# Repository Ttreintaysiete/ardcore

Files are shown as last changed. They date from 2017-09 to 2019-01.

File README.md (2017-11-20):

# Eurorack Ardcore 2017
This is the repository for the tuned sketches, schematics and board files of the new 2017 version 20Objects Ardcore. The Ardcore is an Arduino based module created by Darwin Grosse as his final work for MS. You can find more information on the orignal project in his website http://20objects.com/ardcore/.

So far there are a couple of versions of the ardcore, the original one by 20Objects which was a PCB only, AFAIK it was intended for dotcom and 5U formats and all the wiring with the panel has to be done manually. This version has 4 AnalogInputs, 2 of them are potentiometers and the other 2 are inputs. It also has 2 digital outputs (i.e. for triggers).

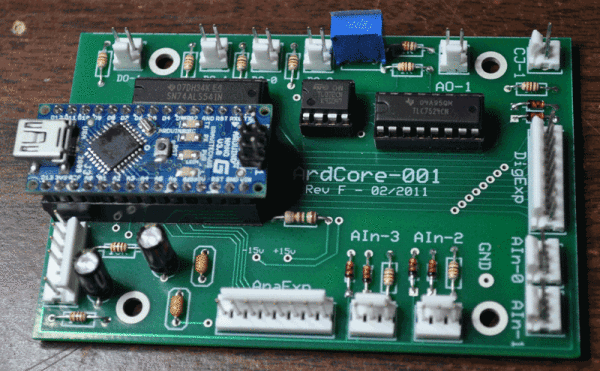
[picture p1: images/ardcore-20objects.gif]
original ardcore


The [original sketches](https://github.com/darwingrosse/ArdCore-Code/commits/master) were first published by Darwin back in 2012. This project originally was a DIY PCB only project.

Later on SnazzyFX published an eurorack format of the module and (as Dan a.k.a. told me) it was long out of stock due its success for a couple of years. 

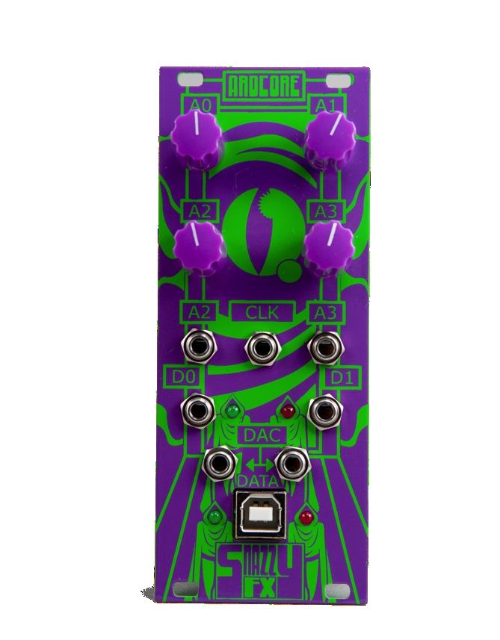
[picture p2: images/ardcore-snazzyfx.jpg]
snazzyfx ardcore


There are plenty of threads in muffwiggler talking about different DIY versions, back in 2013 we made our own version for bananas.

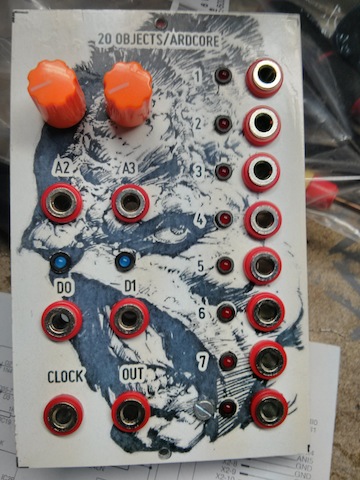
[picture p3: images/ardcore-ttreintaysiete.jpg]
snazzyfx ardcore


The Ardcore is not so well known module but its a power house due its flexibility, it has several sketches that are very usefull and fun to play, but more important the Ardcore is a module that tries to embed the Arduino philosophy into the modular synthesizer community which is to allow musicians, artists and engineers to easly create microcontroller based modules.

Due its digital nature, the ardcore is very good for creating CV sources that are otherwise more complex to create with hardware (like a drunken walk), but it also can create audio with the DAC.

# Our implementation of Ardcore

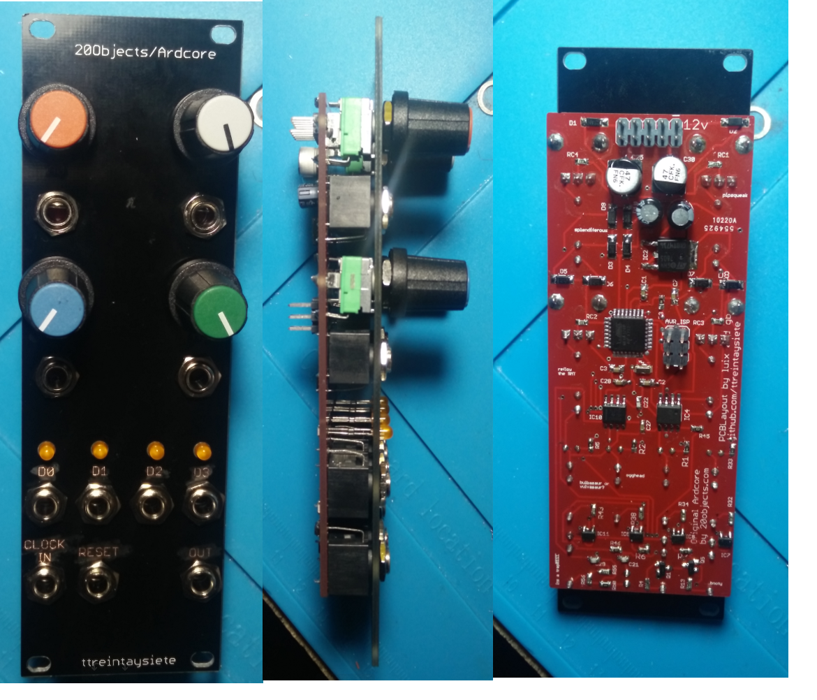
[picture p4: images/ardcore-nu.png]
nu ardcore


So we decided to make a skiff friendly, DIY Ardcore with several improvements:

* double the number of __analog inputs__. So now each AnalogInput has a potentiometer that is normalized to 5v when nothing is connected, when you plug something into the corresponding jack you can still use the potentiometer to attenuate the incommin signal. All analog inputs are protected with diodes (1n4148) so voltage will be cliped to the microcontroller range always (0v-5v). In any case you can use the pot as mentioned to attenuate the incomming signal.

* double the number of __digital outputs__. The original ardcore had 2 digital outputs, in this version we put D2 and D3 for a total of 4. This outputs are driven by the Tristate buffer widely used in digital modules like Mutable Instruments, so you can both isolate microcontroller pin from the outside world at the same time to upscale the voltage and buffer it. So if you plug an output signal into the digital outputs you can't damage the micro controller.

* double the number of __digital inputs__, the original and snazzy Ardcore had 1 multipurpouse digital input labeled as "clock". This input is connected to a pin in the micro controler with support for interrupts which are very usefull when you want to have "responsive" or non blocking behaviours on your sketch. In the new ardcore we added a second digital input labeled __RESET__ which is also connected to another interrupt pin. All the existing sketches were created for the previous hardware versions of the ardcore so they __don't__ use this pin.

* Upgraded DAC, from parallel to SPI and from 8bit to 12bit. This upgrade was both a must go mainly because of the size of the IC and that its easy to source it, also the PCB has less trace (since parallel communication uses 8 connections from atmega328 to the DAC, in comparison with the SPI that only uses 3 wires.

* 8hp Skiff friendly.

# The bad things

Some of the decissions taken during the pcb design have downsides.

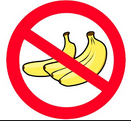
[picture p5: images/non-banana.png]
no more fruit-of-love


* This version of the Ardcore is __non-banana friendly__ :( ... we are very sorry for this because we have many modules in bananas and love them, but it was a design decision to make it work with the disconnections on the minijacks. This is by far (in our opinion) the biggest downside.

* When upgrading the DAC from parallel to SPI we lose all the "bit" traces from the parallel connections, so its not possible to easly create an expander for this version of the module.

* Another problem from upgrading the DAC is that the original sketches that used it, need a small tweak on the code in order to work properlly. This is based on the Euroardcore but with the mcp4921

  * you need to add to the beggining of any sketch using the DAC,
    ```
    #include <SPI.h>
    #include <DAC_MCP49xx.h>
    DAC_MCP49xx dac(DAC_MCP49xx::MCP4921, 10);
    ```
  * also you need to add the following code at the end of the __setup()__ so the DAC is properlly initialized:
    ```
    dac.setBuffer(true);        //  Set FALSE for 5V vref.
    dac.setGain(1);             //  "1" for 5V vref. "2" for 2.5V vref.
    dac.setPortWrite(true); 
    ```
  * and finally replace the __dacOutput()__ and __dacOutputfast()__ to be something like:
    ```
     void dacOutput(long v)
    {
      dac.outputA(v);
    }
    ```

* No USB, need a programer.. the original Ardcore had either an arduino nano or a ftdi IC with USB on the board, so you can directly upload your sketches. With this version you need an external programmer that uses ISP, we recommend the official [AVRISP mkii](http://www.atmel.com/tools/avrispmkii.aspx).

# License:

This software and hardware is licensed under the Creative Commons __Attribution-NonCommercial__ license. This license allows you to tweak and build upon the code for non-commercial purposes, without the requirement to license derivative works on the same terms. If you wish to use this (or derived) work for commercial work or usage of the PCBS, please contact 20 Objects LLC its website (www.20objects.com).

For more information on the Creative Commons CC BY-NC license, visit http://creativecommons.org/licenses/

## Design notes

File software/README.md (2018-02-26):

# MCP Library

In order to compile sketches using the MCP49 DAC, you have to download the library [here](https://github.com/downloads/exscape/electronics/Arduino_DAC_MCP49x1_v1.0.zip) and install it in your Arduino library. Also note that some instructions used in the fac_drums were deprecated on the newest Arduino IDE, so you need to compile and upload them on the older.

You need to do a small tweak on the code in order to work properlly, this is because this new DAC uses SPI. This is based on the Euroardcore but with the mcp4921 has [been fully tested](https://www.youtube.com/watch?v=P1rAHDsiEtc):

  * you need to add to the beggining of any sketch using the DAC,
    ```
    #include <SPI.h>
    #include <DAC_MCP49xx.h>
    DAC_MCP49xx dac(DAC_MCP49xx::MCP4921, 10);
    ```
  * also you need to add the following code at the end of the __setup()__ so the DAC is properlly initialized:
    ```
    dac.setBuffer(true);        //  Set FALSE for 5V vref.
    dac.setGain(1);             //  "1" for 5V vref. "2" for 2.5V vref.
    dac.setPortWrite(true); 
    ```
  * and finally replace the __dacOutput()__ and __dacOutputfast()__ to be something like:
    ```
     void dacOutput(long v)
    {
      dac.outputA(v);
    }
    ```

# Compiling the sketches of this repo

I'm using __arduino 1.0.6__ to compile all fac_drum sketches, it may be possible to use newer arduino versions on the rest of the sketches.

In the __libraries__ folder you can find the library I'm currently using to compile all the sketches with the MCP (dac).

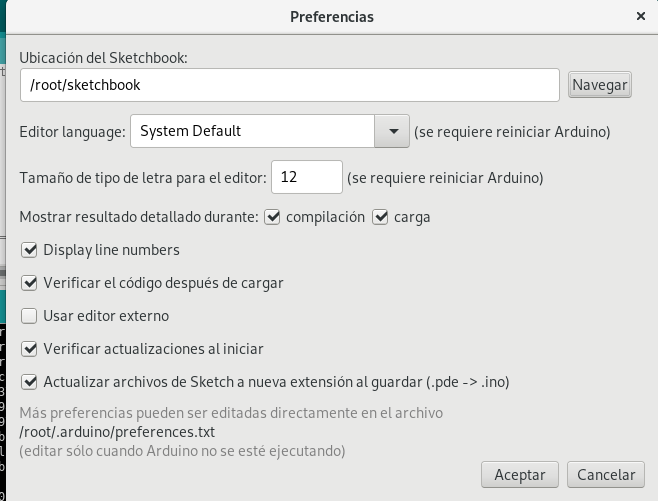
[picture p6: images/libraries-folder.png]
lib configuration ardcore


In my case I'm using Arduino with sudo command (to let read/write USB ports for the programmer), so my __sketbook__ is located at __/root/sketchbook__ and here is were I coped the DAC_MCP49xx library.

```
[root@boxita sketchbook]# tree
.
└── libraries
    ├── DAC_MCP49xx
    │   ├── DAC_MCP49xx.cpp
    │   ├── DAC_MCP49xx.h
    │   ├── examples
    │   │   ├── MCP49x1_single_demo
    │   │   │   └── MCP49x1_single_demo.ino
    │   │   └── MCP49x2_dual_demo
    │   │       └── MCP49x2_dual_demo.ino
    │   ├── keywords.txt
    │   └── README.txt
    └── readme.txt

5 directories, 8 files
[root@boxita sketchbook]# 
```

# Uploading hex using __avrdude__ and your AVRISP mkII.

To upload the file directly you can try the following command, I'm doing this on linux (Arch) so depending on your system configuration you may need to __sudo__ the command. Remember to burn the fuses as explained in the building guide.

```
$ avrdude -c avrispmkII -p ATmega328P -e -U flash:w:fac_fm_osc.cpp.hex
```

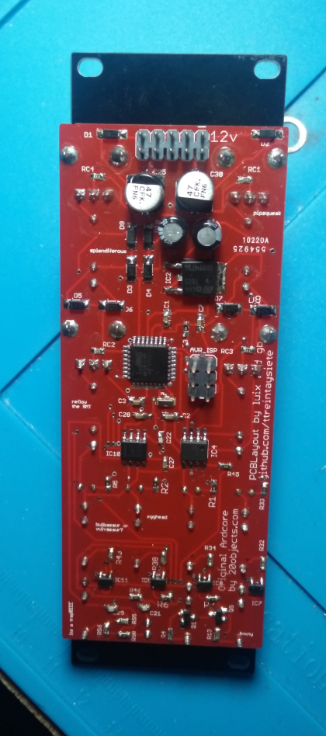
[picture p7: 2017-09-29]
images/ardcore-nu-back.png

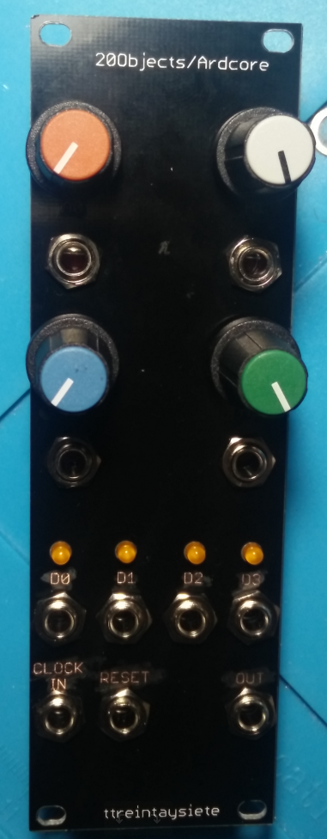
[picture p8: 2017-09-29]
images/ardcore-nu-frontal.png

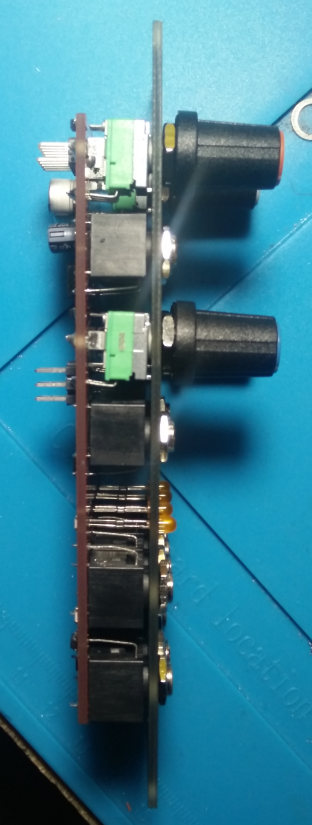
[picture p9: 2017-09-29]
images/ardcore-nu-side-skiff.png

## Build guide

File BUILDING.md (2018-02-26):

# Bill of Materials

This is the mouser [BOM](https://www.mouser.es/ProjectManager/ProjectDetail.aspx?AccessID=9c269e6775), but here is the detail anyway because you are so lazy to copy paste it into a mouser project/cart :P

Suggested Part | Qty | Value | Parts | Description
---------------| --- | ----- | ----- | ------------
[9mm Alpha pots](https://www.thonk.co.uk/shop/alpha-9mm-pots-dshaft/) | 4 | 10k | ALPS_POT_VERTICAL       
[thonkicons](https://www.thonk.co.uk/shop/3-5mm-jacks/) | 11 | WQP-PJ301M-12_JACK | WQP-PJ301M-12_JACK      
n/a | 1 | Header 3x2 | AVR_ISP | Header 3x2
n/a | 1 | Header 5x2  | JP1 | Header 5x2
n/a | 4 | LED3MM | LED1, LED2, LED3, LED4  LED
81-GRM188R71H104JA3D | 6 | 100n | C1, C2, C3, C7, C27, C28 | CAPACITOR, European symbol
81-GRM1885C1H101GA1J | 2 | 100p | C21, C22 | CAPACITOR, American symbol
667-EEE-FK1C470P | 2 | 47u | C25, C30 | POLARIZED CAPACITOR, American symbol
81-GRM39C470J50 | 1 | 47p | C29 | CAPACITOR, American symbol
667-ECE-A1VKS100 | 3 | 10u | C4, C5, C6 | POLARIZED CAPACITOR, European symbol
621-1N5819HW-F | 2 | 1N5819HW | D1, D2 | DIODE
78-1N4148W-E3-08 | 8 | 1n4148 | D3, D4, D5, D6, D7, D8, D9, D10 | 1N4148 General Purpose Rectifie
595-TL072CD | 1 | TL072 | IC10 | OP AMP
511-L7805CDT-TR | 1 | 7805DT | IC2 | Positive VOLTAGE REGULATOR
579-MCP4921-E/SN | 1 | MCP4921 | IC4 
595-SN74AHCT1G125DBV | 4 | 74AHCT1G125DBV | IC5, IC7, IC8, IC11 | Single Bus Buffer Gate with 3-State Output
556-ATMEGA328P-AU | 1 | ATMEGA328P-AU | IC6 
863-MMBT3904LT1G | 2 | SOT23-BEC | Q1, Q5 | NPN Transistror
652-CR0603FX-2200ELF | 4 | __100 to 220__ | R1, R2, R5, R33 | Resistor for LEDS, so depends on your leds color.
652-CR0603FX-1002ELF | 3 | 10k | R3, R6, R7 | RESISTOR, American symbol
652-CR0603-FX-1003GLF | 3 | 100k | R4, R13, R56 | RESISTOR, American symbol
652-CR0603FX-3902ELF | 2 | 39k | R45, R46 | RESISTOR, American symbol
652-CR0603FX-4702ELF | 1 | 47k | R50 | RESISTOR, American symbol
652-CR0603-FX1001HLF | 9 | 1K | RC1, RC2, RC3, RC4, R32, R34, R38, R43, R55 | RESISTOR, European symbol
81-CSTCE16M0V53-R0 | 1 | RESONATOR | Y1 | Resonator

# Building your Ardcore

1. Solder all the power components as show in the picture:

   * Atmega328P-AU
   * SMD Resonator - this is the equivalent of a Crystal Oscillator plus the 2 x 22pf caps widely used in arduino boards but in a single package.
   * IC2 - 5V regulator 
   * D1, D2 - 1n5819
   * C4 (on the front side), C5, C6,  - 10u eletrolitic caps
   * C25, C30 - 47u electrolic caps
   * R3 a 10k resistor for the MC reset
   * C1, C2, C3, C7 - 100n ceramic caps
   * ISP pin header for programming
   * 2x5 pin header for power

   power supply components

2. test the power on the board, plug the eurorack power supply cable and check that nothing gets too hot, if you have a current measure tool its also a good practice to measure the module current consumption which should be a few milliamps. If you detect your module is compsuming more than 200mha then something is wrong. This way of testing your module is much better than directly plugin it into your euorack system so you avoid any damages to the rest of your modules.

3. Now its time to change the __fuses__ of the Atmega328P-AU remember you need to plug your Ardcore to your eurorack power supplyg (ribbon cable), this is important because by default the microcontrollers uses its internal oscillator (which is not very accurate, but its free), to use an external oscillator you should use the avrdude tool and this command and your AVRPISP-mkii programer:

```
[luix@boxita ardcore]$ sudo avrdude -c avrispmkII -p m328p -U lfuse:w:0xFF:m -U hfuse:w:0xDA:m -U efuse:w:0x05:m
[sudo] password for luix: 

avrdude: AVR device initialized and ready to accept instructions

Reading | ################################################## | 100% 0.00s

avrdude: Device signature = 0x1e950f (probably m328p)
avrdude: reading input file "0xFF"
avrdude: writing lfuse (1 bytes):

Writing | ################################################## | 100% 0.01s

avrdude: 1 bytes of lfuse written
avrdude: verifying lfuse memory against 0xFF:
avrdude: load data lfuse data from input file 0xFF:
avrdude: input file 0xFF contains 1 bytes
avrdude: reading on-chip lfuse data:

Reading | ################################################## | 100% 0.00s

avrdude: verifying ...
avrdude: 1 bytes of lfuse verified
avrdude: reading input file "0xDA"
avrdude: writing hfuse (1 bytes):

Writing | ################################################## | 100% 0.01s

avrdude: 1 bytes of hfuse written
avrdude: verifying hfuse memory against 0xDA:
avrdude: load data hfuse data from input file 0xDA:
avrdude: input file 0xDA contains 1 bytes
avrdude: reading on-chip hfuse data:

Reading | ################################################## | 100% 0.00s

avrdude: verifying ...
avrdude: 1 bytes of hfuse verified
avrdude: reading input file "0x05"
avrdude: writing efuse (1 bytes):

Writing | ################################################## | 100% 0.01s

avrdude: 1 bytes of efuse written
avrdude: verifying efuse memory against 0x05:
avrdude: load data efuse data from input file 0x05:
avrdude: input file 0x05 contains 1 bytes
avrdude: reading on-chip efuse data:

Reading | ################################################## | 100% 0.00s

.....

avrdude done.  Thank you.

[luix@boxita ardcore]$
```

4. Since its an Arduino based project, and it the atmega328p-au comes completely blank we have to burn the bootloader, you need to chose the board "Arduno NANO w/Atmega328" on the board menu, and change your programmer to "AVRIS-mkii" on the programmer menu. To burn the bootloader  "Tools -> Burn bootloader".

5. If everything goes OK with the bootloader now you can upload sketches, you can try to upload the [__test__](https://github.com/Ttreintaysiete/ardcore/tree/master/software/sketches/ardcore-pot-led-test) sketch we have prepared, this sketch lets you __TEST__ the LEDS, AnalogInputs and Digital Outputs, its a sort of "cheap and dirty" clock divider just mean for testing the module. It has an internal clock, it doesn't accept external clock nor uses the DAC to output anything.

6. At this point you should solder the rest of the components and check that it works with the __test sketch__. Remember to solder the jacks and the pots the last, use the panel to correctly align all the components and then solder them.

7. When you finish soldering all the components you should test your module using an sketch that uses the CLOCKIN and DAC, like th [__FAC drums__](https://github.com/Ttreintaysiete/ardcore/tree/master/software/sketches/fac_drums).

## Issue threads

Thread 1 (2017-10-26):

74AHCT1G125DBV replacement?

hedefalk, 2017-10-26:
Hi, I'm trying to source parts on a shoestring for a couple of units of this. I'm trying to avoid mouser and similar because of shipping. The only thing that was a bit problematic is the 74AHCT1G125DBV. It's not easily available on the surplus sources I'm using (mostly just aliexpress and ebay). Seems like the SOT-353 package is a lot easier to get cheap:

https://www.aliexpress.com/item/Free-Shipping-50PCS-lot-74AHCT1G125SE-7-IC-BUS-BUFF-3ST-SGL-N-INV-SOT353-125-74AHCT1G125/32682004541.html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,searchweb201602_4_10152_10065_10151_10344_10068_10345_10342_10343_10340_10341_10171_10541_10084_10083_10307_10301_5640015_10303_10060_10155_10154_10056_10055_10539_10538_5370015_10537_10312_10536_10059_10313_10314_10534_10533_100031_10103_10073_10102_10142_10107,searchweb201603_1,ppcSwitch_5&btsid=7003e7aa-5e92-4a2a-a64d-ae9a055d2782&algo_expid=900eb61a-5ea6-4e61-8745-6672c314c970-0&algo_pvid=900eb61a-5ea6-4e61-8745-6672c314c970

74AHCT1G125DBV is SOT23-5

Maybe for the next iteration :) Do you happen to know if there are any other replacements?

Thanks a lot for this work!

beeva-luisgonzalez, 2017-10-26:
Hi!
first of all thanks a lot for your message and taking time for the suggestion. This is the Mouser BOM ill be adding to the doc:

https://www.mouser.es/ProjectManager/ProjectDetail.aspx?AccessID=9c269e6775

I totally agree with all your arguments, but we wanted to make this project easy to build for anyone regarding its DIY level, so having a single "no brainer" mouser cart is the best for most cases...

Mouser is free shipping when you purchase 50€ or more which seems reasonable as your probably know, but we will consider changing this if we find a similar part in SOT-353 that is compatible.

We are using this part mainly because we copied (and trust) Mutable Instruments designs.. since Oliver uses this on most its designs.

hadesbox, 2017-10-26:
and please let us know how your build went... if you have any suggestions for the board or anything else... we tried to make it super easy to build silkscreen was carefully placed, all components have enough (we hope) space etc...

hedefalk, 2017-10-26:
Will do!

hedefalk, 2017-10-26:
I'll close the issue so it doesn't look like you're having a bug :)

hedefalk, 2017-10-26:
Just one more thing when I have you on the line :)

You recommend the AVRPISP mk2, is there a reason I can't just use an arduino as ISP, like instructions here https://www.arduino.cc/en/Tutorial/ArduinoISP

hadesbox, 2017-10-27:
@hedefalk ArduinoISP will work just fine! Its just a bit slower and if you plan to do some serious programming its better to us AVRISP mk2, but otherwise using a second arduino as programmer is fine... I'll add your link to the "programming" section as an alternative!

hadesbox, 2017-10-27:
Ohh one thing you need to test is how to change the fuses of the atmega328 because by default it has the fuses to use its internal oscillator, I added to the building doc how to do it with avrispmkii and avrdude, dont know how to do it with ArduinoISP solution... should work!

hedefalk, 2017-10-27:
Great, thanks!

Closed 2017-10-26.

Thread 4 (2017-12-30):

Placement exact between panel and component pcb?

hedefalk, 2017-12-30:
Got my PCB's from China the other day (yey!) and started on a front panel. I'm 3d printing and designing in openscad. I couldn't find a decent ruler so I extracted the values from the panel eagle file here. I noticed that the LED's are a bit displaced. My OCD wants to fix this, in your experience, would there be any problem in aligning them perfectly with the jacks and just bending in place? Should be fine right?

The other issue is that also the jacks a tiny amount misplaced too as seen here:

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

I guess they are on the PCB too, that you used the same positions? I have my caliper and good rulers at work so I'm eyeballing…

Need to reinforce with extra plastic inbetween the thonkiconns or the panel isn't stiff enough and bends so I really need all the room I can get…

One more piece of feedback/question - the front side 10uF electrolytic - the ones I have stocked have a taller footprint than the thonkiconns so needed to bend it in place. Did you use smaller caps?

Thanks a lot for sharing this pcb <3

hadesbox, 2018-01-02:
Hi @hedefalk you are totally right no everything, the hole are misplaced on both pcb and panel, I will fix this on next board revision.. but your boards and panels will work! all the tests we have done fit perfectly regardless of the small miss align.

Regarding the 10uF cap, if you use the value listed on the [BOM](https://github.com/Ttreintaysiete/ardcore/blob/master/BUILDING.md), you should not have a problem is a short lengthed cap so no bending is needed. The part is [this and its 5mm](https://www.mouser.es/productdetail/panasonic/ece-a1vks100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) .

hadesbox, 2018-01-02:
Check the images I posted here https://imgur.com/gallery/Asrzm

hadesbox, 2018-01-02:
BTW if you want to share your panel please consider making a pull request as the one I designed is super simple and ugly.

hedefalk, 2018-01-02:
@hadesbox Ah, right, I didn't actually use the BOM as a shopping cart come to think of it :) The electrolytics I had was taller, but they fitted if I bent them.

I'm only half way through with my first Ardcore and currently away from all my stuff until 8 jan. I'll test the panel design thoroughly and then I can PR it as an STL or put up on thingiverse if you want. It's just a basic 3d print though, no markings or anything. I typically sand the front, spray paint black and hand paint the markings, white really no fancy stuff.

I'm considering getting screen printing gear. I'm really into white on black like old Moog's but I don't like the PCB panels much.

Closed 2018-01-08.

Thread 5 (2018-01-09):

Can't seem to burn fuses…

hedefalk, 2018-01-09:
I'm still waiting for a "real" AVR programmer to arrive but hooked up a Nano in the meantime. Maybe my problems are related to this, but I'll ask just if you recognize these issues:

So I have an Arduino ISP hooked up that's running the official ArduinoISP sketch. I've mounted components according to the first step here:

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

I'm then trying to set the fuses with something like:

```
~ ❯❯❯  avrdude -c arduino -b  19200 -p m328p -P /dev/tty.wchusbserial1450 -U lfuse:w:0xFF:m -U hfuse:w:0xDA:m -U efuse:w:0x05:m                                                    ⏎

avrdude: stk500_getsync() attempt 1 of 10: not in sync: resp=0x15
avrdude: stk500_getsync() attempt 2 of 10: not in sync: resp=0x15

avrdude: stk500_getparm(): (a) protocol error, expect=0x14, resp=0x14

avrdude: stk500_getparm(): (a) protocol error, expect=0x14, resp=0x01
avrdude: stk500_initialize(): (a) protocol error, expect=0x14, resp=0x10
avrdude: initialization failed, rc=-1
         Double check connections and try again, or use -F to override
         this check.

avrdude: stk500_disable(): unknown response=0x12

avrdude done.  Thank you.
```

I'm going to dig deeper into the Arduino stuff how to properly do this, feels like the usb connection on osx/arduino is pretty unstable. I get different errors using different baudrates too… Anyways, just wanted to check if this is something you recognized?

hadesbox, 2018-01-09:
Depending on your linux distro and avrdude installation you may need to sudo that command!

also check that the /dev/tty.wchusbserial1450 is the correct device.. you can unplug the arduino nano, then use the __dmesg__ command to see the actual device name.

Also fuses are to let know the atmega328 it should use an external crystal which is more precise than the internal, this means that you can still BURN an arduino sketch to your ardcore (for instance the testing sketch or the blinking led sketch) and see if it works.

The only behavior you will get by not setting the fuses is that the sketch will look like if runs slower because of the internal atmega328 oscillator.

hadesbox, 2018-01-09:
Also triple check that you connected the right pins of the header, as some may be swapped.

https://www.arduino.cc/en/Tutorial/ArduinoISP

I used the avrisp-mkii these are the headers

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

hadesbox, 2018-01-09:
Also check this http://heliosoph.mit-links.info/arduinoisp-reading-writing-fuses-atmega328p/

hadesbox, 2018-01-10:
Check the

hedefalk, 2018-01-10:
@hadesbox Thx for tips! I'm unfortunately home with sick kids and away from "stuff" again so can't do much right now, but I'll be back!

hedefalk, 2018-01-11:
Thanks for all the help!

I've finally gotten so far that I can program other Arduinos via the ISCP header with my little homebrewed programmer. Seems what was missing was a way for me to switch between being programmed and being programmer so I added a cap between reset and gnd on the programmer that is connected via a jumper so I can pull it out if I need to reprogram the actual programmer again:
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

Before that I had all sorts of problems of the programmer being programmed and such.

So I've mostly experimented with ArduinoIDE, but with verbose output I can see the avrdude commands so it turned out when using the "Arduino as ISP" programmer in the UI it uses stk500v1 as programmer argument.

So I now I tried using the settings that have been successful but with the fuses update commands:

```

~/d/p/flatcam ❯❯❯ avrdude -v -p atmega328p -b 19200 -P /dev/cu.wchusbserial213240 -c stk500v1 -U lfuse:w:0xFF:m -U hfuse:w:0xDA:m -U efuse:w:0x05:m                                                      master

avrdude: Version 6.3, compiled on Sep 18 2017 at 20:31:51
         Copyright (c) 2000-2005 Brian Dean, http://www.bdmicro.com/
         Copyright (c) 2007-2014 Joerg Wunsch

         System wide configuration file is "/usr/local/Cellar/avrdude/6.3/etc/avrdude.conf"
         User configuration file is "/Users/viktor/.avrduderc"
         User configuration file does not exist or is not a regular file, skipping

         Using Port                    : /dev/cu.wchusbserial213240
         Using Programmer              : stk500v1
         Overriding Baud Rate          : 19200
         AVR Part                      : ATmega328P
         Chip Erase delay              : 9000 us
         PAGEL                         : PD7
         BS2                           : PC2
         RESET disposition             : dedicated
         RETRY pulse                   : SCK
         serial program mode           : yes
         parallel program mode         : yes
         Timeout                       : 200
         StabDelay                     : 100
         CmdexeDelay                   : 25
         SyncLoops                     : 32
         ByteDelay                     : 0
         PollIndex                     : 3
         PollValue                     : 0x53
         Memory Detail                 :

                                  Block Poll               Page                       Polled
           Memory Type Mode Delay Size  Indx Paged  Size   Size #Pages MinW  MaxW   ReadBack
           ----------- ---- ----- ----- ---- ------ ------ ---- ------ ----- ----- ---------
           eeprom        65    20     4    0 no       1024    4      0  3600  3600 0xff 0xff
           flash         65     6   128    0 yes     32768  128    256  4500  4500 0xff 0xff
           lfuse          0     0     0    0 no          1    0      0  4500  4500 0x00 0x00
           hfuse          0     0     0    0 no          1    0      0  4500  4500 0x00 0x00
           efuse          0     0     0    0 no          1    0      0  4500  4500 0x00 0x00
           lock           0     0     0    0 no          1    0      0  4500  4500 0x00 0x00
           calibration    0     0     0    0 no          1    0      0     0     0 0x00 0x00
           signature      0     0     0    0 no          3    0      0     0     0 0x00 0x00

         Programmer Type : STK500
         Description     : Atmel STK500 Version 1.x firmware
         Hardware Version: 2
         Firmware Version: 1.18
         Topcard         : Unknown
         Vtarget         : 0.0 V
         Varef           : 0.0 V
         Oscillator      : Off
         SCK period      : 0.1 us

avrdude: AVR device initialized and ready to accept instructions

Reading | ################################################## | 100% 0.08s

avrdude: Device signature = 0x000000 (retrying)

Reading | ################################################## | 100% 0.08s

avrdude: Device signature = 0x000000 (retrying)

Reading | ################################################## | 100% 0.08s

avrdude: Device signature = 0x000000
avrdude: Yikes!  Invalid device signature.
         Double check connections and try again, or use -F to override
         this check.

avrdude done.  Thank you.
```

At least some progress for me :) I'll have to dig further…

hedefalk, 2018-01-11:
Seems I can actually use arduino as programmer too. Anyway, just reading the fuses from say an arduino pro mini, I get:

```
~/d/p/flatcam ❯❯❯ avrdude -p atmega328p -b 19200 -P /dev/cu.wchusbserial213240 -c arduino                                                                                                                master

avrdude: AVR device initialized and ready to accept instructions

Reading | ################################################## | 100% 0.03s

avrdude: Device signature = 0x1e950f (probably m328p)

avrdude: safemode: Fuses OK (E:FD, H:DA, L:FF)

avrdude done.  Thank you.
```

An Arduino Uno:

```
~/d/p/flatcam ❯❯❯ avrdude -p atmega328p -b 19200 -P /dev/cu.wchusbserial213240 -c arduino                                                                                                                master
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
hedefalk, 2018-01-12:
Could you elaborate on the reason I need external power other than the ICSP one? I you know that is, or maybe just from experience?

hadesbox, 2018-01-12:
Because I didnt connect that trace into the Atmega. It was a design decission .. .because its dangerous to have the ISCP header and the +5V from rail together, if I wanted to have both then I need to add a jumper to make a switch so the user can select where from he wants to powers the MCU from the USB of the programmer or the eurorack power.

hedefalk, 2018-01-12:
Yey! Fuses read!

```
~ ❯❯❯ avrdude -p atmega328p -b 19200 -P /dev/cu.wchusbserial212240 -c stk500v1                                                                                                   ⏎

avrdude: AVR device initialized and ready to accept instructions

Reading | ################################################## | 100% 0.08s

avrdude: Device signature = 0x1e950f (probably m328p)

avrdude: safemode: Fuses OK (E:FF, H:D9, L:62)

avrdude done.  Thank you.
```

This with only ISCP though. The +5V is actually connected :)

It was bad soldering again. I was really really sure I had tested this thorough but apparently not. I checked (thought it was triple checking) the connection of each ICSP pin header to the top of the legs on the MCU and noticed that the SCK wasn't soldered properly on the MCU.

Thanks for all the help!

hadesbox, 2018-01-12:
Then thats it! :) I could be mistake on the power thing I said, but generally we burn the arduino sketch with the power up.

hedefalk, 2018-01-12:
@hadesbox ok, cool! Do you manufacture a lot of these?

Anyway, now settings fuses I get some safemore verification error, is this fine?

```
~ ❯❯❯ avrdude -p atmega328p -b 19200 -P /dev/cu.wchusbserial212240 -c stk500v1 -U lfuse:w:0xFF:m -U hfuse:w:0xDA:m -U efuse:w:0x05:m

avrdude: AVR device initialized and ready to accept instructions

Reading | ################################################## | 100% 0.08s

avrdude: Device signature = 0x1e950f (probably m328p)
avrdude: reading input file "0xFF"
avrdude: writing lfuse (1 bytes):

Writing | ################################################## | 100% 0.08s

avrdude: 1 bytes of lfuse written
avrdude: verifying lfuse memory against 0xFF:
avrdude: load data lfuse data from input file 0xFF:
avrdude: input file 0xFF contains 1 bytes
avrdude: reading on-chip lfuse data:

Reading | ################################################## | 100% 0.03s

avrdude: verifying ...
avrdude: 1 bytes of lfuse verified
avrdude: reading input file "0xDA"
avrdude: writing hfuse (1 bytes):

Writing | ################################################## | 100% 0.08s

avrdude: 1 bytes of hfuse written
avrdude: verifying hfuse memory against 0xDA:
avrdude: load data hfuse data from input file 0xDA:
avrdude: input file 0xDA contains 1 bytes
avrdude: reading on-chip hfuse data:

Reading | ################################################## | 100% 0.03s

avrdude: verifying ...
avrdude: 1 bytes of hfuse verified
avrdude: reading input file "0x05"
avrdude: writing efuse (1 bytes):

Writing |                                                    | 0% 0.00s ***failed;
Writing | ################################################## | 100% 0.21s

avrdude: 1 bytes of efuse written
avrdude: verifying efuse memory against 0x05:
avrdude: load data efuse data from input file 0x05:
avrdude: input file 0x05 contains 1 bytes
avrdude: reading on-chip efuse data:

Reading | ################################################## | 100% 0.03s

avrdude: verifying ...
avrdude: verification error, first mismatch at byte 0x0000
         0xfd != 0x05
avrdude: verification error; content mismatch

avrdude: safemode: efuse changed! Was 5, and is now fd
Would you like this fuse to be changed back? [y/n]
```

hadesbox, 2018-01-12:
Its fine that error. Im not super sure why the programmer sometimes can't verify everything, but fuses are set fine so its ok.

Burn the test sketch, for this you will need to put the potentiometers and the leds.

hedefalk, 2018-01-12:
Great, thanks!

Closed 2018-01-12.

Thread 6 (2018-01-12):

Tuning in software?

hedefalk, 2018-01-12:
Oh, maybe stupid question, but I just realized I only have 24k and no 24.9k 0603's so I looked closer at the schematic to see if it would be important and noticed that it's on the DAC output. So yeah.

And then I thought, but well, there ought to be a trimpot for tuning there. But there isn't? How would I go about tuning this one for a sketch like a quantizer which is my first intended use case? I guess I'd need to tune in software instead, possibly using the analog pots then and store in mem? Is there any code examples on this? I thought this was gonna be pretty compatible with original ardcore sketches. NP though, I guess it's fixable and I mostly wanna do my own software anyways, just wanted to know how you approached it?

hadesbox, 2018-01-13:
Hi! So the ardcore its really fully compatible with all the sketches, you just need to change the DAC as specified so dont get scared there... The original arduino didn't have a stable voltage reference for the dac, this version does so you should be fine without any calibration.

In any case if you want to make super fine adjustments you can do it but cutting a trace and adding the trimmer.

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

So cutting in the trace in purple and changing the 100k resistor for a 80k resistor, and having a 50k trimmer should more than enough.

If you check the schematics on the original ardcore you can see how its wired... its to the resistor on the output to change the offset of dac... and thats it.

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

If you use the 24.9k you should not need to do anything of these, please test first and let us know how it went. I really never have need to do any adjustments.

hadesbox, 2018-01-13:
If you see the "euroardcore" it doesnt' have any trimmers too.

http://syinsi.com/projects/euroardcore/euroardcore-building-guide/

hadesbox, 2018-01-13:
in our "Old" ardcore

hadesbox, 2018-01-13:
Anyway if you want to try to make a software calibration you should try to use Braids (mutable instruments) algorithm.

https://github.com/pichenettes/eurorack/blob/2e09d0c20452763366d8aa490e41ac987fc0ebad/braids/ui.cc#L169-L180

Its the most copied algorithm from Olivier :). Its not super simple to implement but works great.. I haven't implement anything of this yet.

hedefalk, 2018-01-13:
@hadesbox Thanks for all the info! Sounds awesome, really want to get started programming this thing soon!

But just want to double check - the schematic I have actually says 47K on R50 and 100k on R56 compared to the build instructions which says 24.9k on R50. That sounds like almost a twice the output amplification?

hadesbox, 2018-01-15:
R50 is 24.9k, I checked on the eagle files and the BOM that I published and 24.9k its correct. What schematic you are using?

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

hadesbox, 2018-01-15:
AHHHHHHHHHH now I remember sorry... bom and building docs are not updated.... the board files are correct, the resistance was increasted to 47K to improve gain on the output (double gain).

https://github.com/Ttreintaysiete/ardcore/commit/5caaa4181be58aee3b772caba368f5d56903072c

Check that commit comment. So with 24.9k works but with lower volume... to double amplitude you should use 47k.

hedefalk, 2018-01-15:
Ah, cool! Thanks! 47K it is!

Closed 2018-01-15.

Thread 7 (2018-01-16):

How it is ok for the regulator and MCU?

hedefalk, 2018-01-16:
Finished building my first unit and I have uploaded the led test sketch. It's working for 3 out of 4 leds:

https://photos.app.goo.gl/aBm5HXirTEnzTL9A3

I used my scope to debug and found that DIO6 wasn't soldered (man I had many bad points on the MCU apparantly). At first I could get the signal on top of the pin but not on the part of the pad that I could reach on the PCB. So I fluxed and resoldered.

After that however, I'm pretty sure that the solder point for DIO6 is ok, however now I don't even get a signal on the pin itself. The MCU is also pretty hot and the regulator is really hot - like "I don't wanna keep my finger on it too long" - hot.

Did I finally managed to fry the MCU?

hadesbox, 2018-01-16:
If its hot, then you have a short on that pin probably... my builds can be powered on for hours and not getting hot.

So check for shorts on that pin (or in the led, or in the jackoutput). Check for shorts agains +12v and -12v .
Its very likely that pin is now dead, RIP.

hadesbox, 2018-01-16:
if you have a amperimeter would be nice to measure wattage of the module... :)

hadesbox, 2018-01-16:
With the potentiometers you should be able to control de speed of each led output, so try that!.

Another thing that is probable, is that the potentiometer for that output (A2) is not sending it signal to the MCU, or that its also shorted some how.

hedefalk, 2018-01-16:
@hadesbox Yeah, ok, pin 10/DIO6 is grounded so that's explains both heat and no led.

However, there aren't any bridges so I guess it really has to be internal to the MCU? Or beneath the chip that I can't see. Or later in the output chain… Gonna inspect the drivers…

hedefalk, 2018-01-16:
Seems I fried my arduino programmer too powering it… :'(

hedefalk, 2018-01-16:
Yey, found it! Bridge on that channels output driver:
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

hadesbox, 2018-01-16:
Yeah could be that via...

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

but you shouldn't have problem becuse vias are tented (should be covered by solder mask).

hadesbox, 2018-01-16:
AHHHHHHH Those little tribufferstate are also a pain to solder, its better to double check them all :)

hedefalk, 2018-01-16:
Now I have 4 blinking LEDs! Yey! However, that one that was didn't blink at all doesn't seem to react to the pots, just blinking constantly slowly.

I'll check the pot reading too…

The LED's are super bright, will change to at least 300ohm or maybe even 400 for the next one. Can hardly see my computer screen right now :) I guess all leds are different, should have breadboarded this batch first :)

Ok, back to pots:

So turning them all up I have on the MCU:

23: 5V
24: 1.6V
25: 5V
26: 5V

which is really weird becuase 24 is A1 which is for D1 in the sketch. However, this one actually does behave differently too. If I understand the sketch and reality, they blink slower the more clockwise (higher voltage) I turn them. A1/D1 however doesn't ever become really slow. And A2/D2 doesn't seem to react to the pot value at all even though that signal actually does come in fine to the MCU.

Love some debugging! At least it's not getting hot anymore :)

hedefalk, 2018-01-16:
Ok, so the pot has still 5V on the viper, but after RC4 it has dropped as opposed to the other pots. I'm gonna check those diodes if I have bridged something there.

hedefalk, 2018-01-16:
One of the diodes turned the wrong way. This is starting to get comedical, every mistake possible I have done :) But all fun and games!

hadesbox, 2018-01-16:
Its normal to make some mistakes... the building docs are not very detailed and assume a lot of things.
But at least is a good way to learn (the hardway) a lot.

hedefalk, 2018-01-16:
Yup, I'm  learning a lot :)

I'll just continue logging my debugging if that's ok.

So now I've turned that diode and I get 5V on all the analog input pins when fully clockwise. But now instead I have on 5V also on pin 25 when all are turned fully CCW - suspecting another wrongly turned diode, to GND this time…

Closed 2018-01-24.

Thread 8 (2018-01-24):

Jumping weird behaviour from DAC output…

hedefalk, 2018-01-24:
Finally I have it working! I burnt my homebrewed AVR programmer but yesterday I got a usbasp in the mail ($1 one from China :) ) so now I'm up and running again. Had some more soldering issues, but now I get stuff out, even from the DAC, but I have really weird behaviours.

To simplify, I have this basic 2s square wave sketch:

```
#include <SPI.h>         // Remember this line!
#include <DAC_MCP49x1.h>

#define SS_PIN 10

DAC_MCP49x1 dac(DAC_MCP49x1::MCP4901, SS_PIN);

void setup() {
  dac.setSPIDivider(SPI_CLOCK_DIV16);
    dac.setPortWrite(true);
}

void loop() {
  dac.output(0);
  delay(2000);
  dac.output(4095);
  delay(2000);
}
```

The output puts out a value when said so but then slowly moves towards ground:

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

Anything you've seen before?

hedefalk, 2018-01-24:
More debugging. What comes out of the DAC is fine. Also what comes out of the first opamp, but the after the second one it's this kind of wave instead of the square.

Not sure I understand everything about the circuit here, but looks like something with caps. I'll double check the cap values if I have messed that up.

hedefalk, 2018-01-24:
But hey wait, I can't have a CAP there and use the DAC for control voltage can I? :) The DAC output i AC coupled?

Have you used this for any kind of CV generation?

hedefalk, 2018-01-24:
Shorting that cap makes it behave as I would have expected.

Ok, got it! It seems to me that changes has been made in this version that makes it unsuitable as a 1V/Oct CV tool, like quantizer, glissando, adsr etc. It has been optimized to be a audio generating tool on the DAC output:

* It's AC coupled
* There is no trimpot for tuning, instead it has fixed resistors to maximize output at around +-12V

Maybe you should add that to README.md. I actually intended this mostly to be using for those kinds of things. I guess I can mod it with a trimpot and short that cap, but a heads up could be useful for the next one in line :)

hedefalk, 2018-01-24:
Hm, I realized I need to offset it too if I want something like 0-5V with full resolution from the DAC… Need TWO trimmers I guess… For the version I have I could set the gain by desoldering R56 and then putting a smaller one in series with a trimmer… But need offset too… Wonder how to fit stuff.

Do you happen to have the original schematics? I can't seem to find them anywhere on the web…

hedefalk, 2018-01-24:
Oh, it's actually inverting the dac output too…

So I can't simply short the cap, then I have a square between -12V and 0V. Ugh.

We'll I could probably pre-invert in software for my intended use cases. Then I could skip the offset…

Hopefully I've just misunderstood something because the mods I need seem to add up to be quite complicated :)

hadesbox, 2018-01-24:
Yeah its optimized for audio... so what cap are you refering to?

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

Maybe we can explain its optimized to audio, and to use a jumper on the  cap to have it DC.

hadesbox, 2018-01-24:
This is the original schematic

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

hadesbox, 2018-01-24:
I'm at the office now but I can tell you how to connect what to achieve the DC coupled

hadesbox, 2018-01-24:
Here is the original schematic

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

hedefalk, 2018-01-24:
Thx for the schematic! 👍

>so what cap are you refering to

C4

Shorting it however makes the signal inverted since we just have on non-inverting buffer followed by an inverting one.

NP, I'll figure something out and report back.

>Then I could skip the offset…
I was naive there I think.

hadesbox, 2018-01-24:
Here are both schematics ordered with opamp input output in the same way.

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

hedefalk, 2018-01-24:
Yeah, the original uses two inverting ones. Two minuses equals plus :)

hadesbox, 2018-01-24:
I found a fix but its suboptimal... it outputs DC with 650mv peak, but its suboptimal...

1. remove C4, C29, C21 and R55.
2. Connect a jumper wire between postive pin of C4 and and output (i.e. pads R55)

This version we did was thinked for audio.... the problem is that original ardcore onlyoutputs DC, and out only outputs AC... and you need both :). But you are totally right we didn't explain this anywhere and for aplications like quantizers wont work on AC.

So what I'm thinking is doing another version with simultaneous AC and DC outputs.. its pretty easy to implement...

hadesbox, 2018-01-24:
Im really sorry for this confusion/problem... we got it completely wrong with the AC/DC

hedefalk, 2018-01-24:
NP :) I'm in it for the learning! And super thankful for all the help! I'll try to digest that fix…

I was thinking in similar lines, bypassing the second opamp, should be enough buffering with one.

Should should be some way to wire it for a 0-5 V output too. I'm thinking just making a simple unity gain buffer of the first one straight from DAC output (which is 0-5V, right?)

hedefalk, 2018-01-24:
I can't see how that could give you 650mv peak… Something I'm missing here. Do you output the full range to the DAC?

```
// Output something slow enough that a multimeter can pick it up.
// Shifts the output between 0 V and <VREF> (5 volts for many, but not
// necessarily!).
// For MCP4911, use 1023 instead of 255.
// For MCP4921, use 4095 instead of 255.
void loop() {
  dac.output(0);
  delay(2000);
  dac.output(4095);
  delay(2000);
}
```

hadesbox, 2018-01-24:
first opamp is buffer, after CAP it becomes AC and its inverted by the second op amp..

I'll test your code because I'm testing with oficial Ardcore "Simple VCO" sketch.

hadesbox, 2018-01-24:
I'm testing with this code

```
#include <SPI.h>
#include <DAC_MCP49xx.h>
DAC_MCP49xx dac(DAC_MCP49xx::MCP4921, 10);

void setup()
{

}

void loop() {
  dac.output(0);
  delay(20);
  dac.output(4095);
  delay(20);
}
```
and another fixe that Manu (from befaco) recommend me and now I have 11v peak... it involves cutting 2 traces and 3 wires :S

hadesbox, 2018-01-24:
for you is working now.. by just bypassing the second opamp? what you got now?

hedefalk, 2018-01-24:
Sorry, I haven't tested anything - my stuff is at the office :) I'm just looking at the schematic.

The official sketches are based on 8 bit dac aren't they so possibly need to up the numbers?

Interesting, can you show that fix?

I'm pretty sure I had 0-5V square on the output from the DAC as well as the first opamp which should be buffer enough. So I'm thinking just adding a 1K output resistor after the first opamp and then straight to output?

Would have been great with a trimpot/jumper solution for the next iteration though so I don't have to label half of them CV and half Audio :)

hadesbox, 2018-01-24:
Yes I'll add the trimmer and fix this AC output thing...

hadesbox, 2018-01-24:
Its basically this gain amp circuit

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

with R1 = 10k and R2 = 100k which uses this formula

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

hadesbox, 2018-01-24:
to achieve this you need to cut one trace on the top (black arrow)

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

and another in the bottom (again black arrow)

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

hadesbox, 2018-01-24:
- jumper on the pink arrows
- 10k resistor goes to ground (blue arrow) 2
- 100k resistor on the botom (out) but unconnected in one side, which needs a cable to pin 2 of 072
- a cable from C29 (in my board) bad that is un connected, to the pin 3 (which is the + opamp input).

its a very messy fix...

hadesbox, 2018-01-25:
So today I tried what you said, and just bypass the second opamp, and connect the output of the buffer to the out-minijack. And I get 5v range DC.

This is way more simple than the previous fix I told you. So removing C21, R50, R55, R56 and adding a jumper is enough.

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
hedefalk, 2018-03-16:
>I would go with 0-5v for fine quantization.

I know I've been talking a lot about 5V, but I think actually I would need to be able to set up to 0-8V for 1V/oct in some cases so would be good to have that. I think the typical use cases are:

* 0-8V for 1V/oct for 8 octaves of pitch
* 0-5V for modulation CV's like adsr or whatever and also pitch if one needs less span but more resolution
* Bipolar 0-10V for audio

>the 5V reference is for setting a "stable" voltage so it can be used by the internal resistor ladder to produce voltages consisntely equal when the DAC receives same values.

Sure! But if I understand the feature, the 2x gain feature in this DAC family isn't usable if one uses 5V as ref though since the max rail is 5.7V or something I think. If one instead have just short of half the supply voltage (2V-somthing) one can control gain in software which is pretty useful for us, isn't it? This is how I understand it at least.

I actually have a panel going out soon with room for this. I'm a little cheap trying to use those 10*10 offers without panelization features and gonna use this monster paper cutter to cut them before soldering. It cuts through 1.6mm glass fiber like butter:
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

Still need to see if my panelization idea works but if it turns out nice I'd be happy to send you 5 for free :) Probably wont be as nice as factory cut, but I think good enough for me…

hadesbox, 2018-03-25:
Hey @hedefalk

I've been comparing the circuit of the MI Peaks with the ardcore, and the output its pretty much the same, except that @pichenettes uses a reference voltage of 10V and without the coupling cap.

I would say that is a nice way to do it, what you think??

MI Peaks
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

Ardcore
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

hadesbox, 2018-03-25:
remember that the Peaks output both CV and Audio :)... I have not measure my peaks, but I guess is 0-10v range the audio.

hedefalk, 2018-03-25:
"Output level: 0 to +8V for envelopes, 10Vpp for LFOs and drum signals."

The schematic says it has +-8V on the output…

I see no trimpots so I actually don't understand how that output stage can support different ranges… Maybe it's something in the DAC, it uses another 16 bit DAC, right? Maybe in that case, one don't care much if one loses one bit of resolution, but in our 12 bit case it's a bit more on the edge I think :)

I'm still though playing with the idea of being able to use that 2x software feature of the 4921 DAC just to keep resolution for different use cases. But then one needs to add another Vref around 2+V or so…

pichenettes, 2018-03-25:
The circuit is designed for -8V to +8V, with voltages 0 to +8V used for unipolar output and -5V to +5V used for bipolar output (so each time, about 50% of the available resolution is not used).

hedefalk, 2018-03-25:
@pichenettes Thanks for the clarification!

In our case we have a 12 bit DAC compared to the 16 bit of the Peaks. If we want 0-8V for 1V/oct and something like +-8V for audio with the same output stage we'd have to lose half the resolution too. In out case that's going from 4096 to 2048 steps. I think that might be pushing it, but I don't really have the experience to tell…

Simple math though, over 8 octaves that's 2^11/8/12 = 21 steps per semitone which would mean 3-4 cents out of tune I guess? Maybe that's alright? But still 2 cents would be better than 4, that's my 2 cents :)

@hadesbox ^

hadesbox, 2018-03-25:
Then.. I'm all in to upgrade the DAC too, and the good news there is a library for the DAC8552 so ppl will be able to upgrade their sketches and use this DAC which is far better the current one. This is a community based, diy project and its to experiment not intended as a product so we can do whatever we want.

https://github.com/RobTillaart/Arduino/tree/master/libraries/DAC8552

@hedefalk the way the bipolar/unipolar is done is all via code, so we will have to publish functions to overwrite the dacOutput which will add some offset and scale the output value, and this should be done when someone is porting the sketch depending if he wants to upload a CV sketch or a audio sketch!

A second output would be nice too, we could output phased sines and stuff... we can call it half-quadrature :D.

I think overall is a good idea... 8552 seems to work on 5v! :) So we could use the 5v as reference too or make a smaller voltage reference.

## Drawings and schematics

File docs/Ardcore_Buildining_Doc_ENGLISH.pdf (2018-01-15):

## RESISTANCES & DIODES

# POLARITY

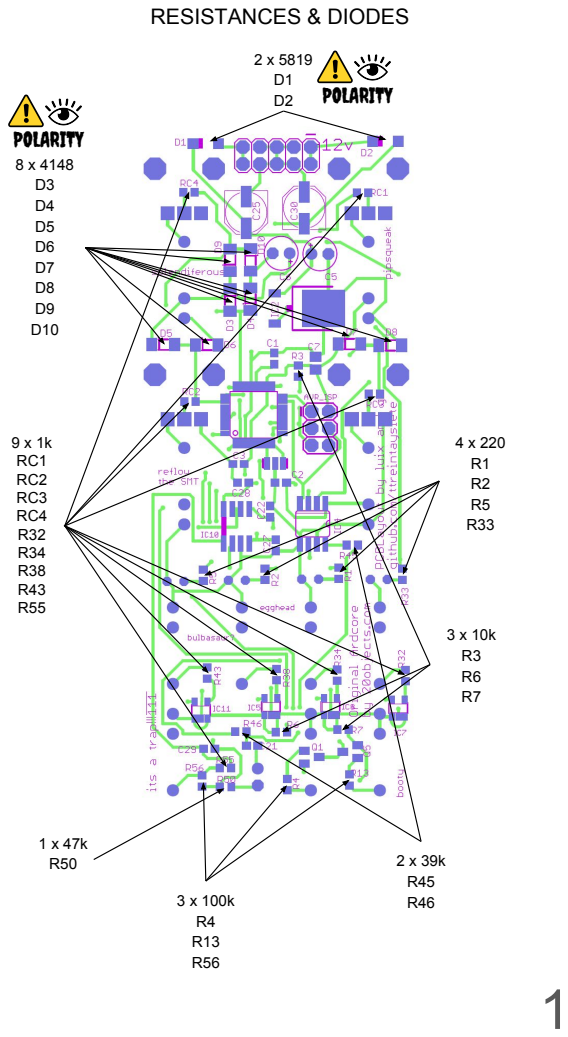
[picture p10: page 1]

## CAPACITORS & IC

POLARITY | POLARITY

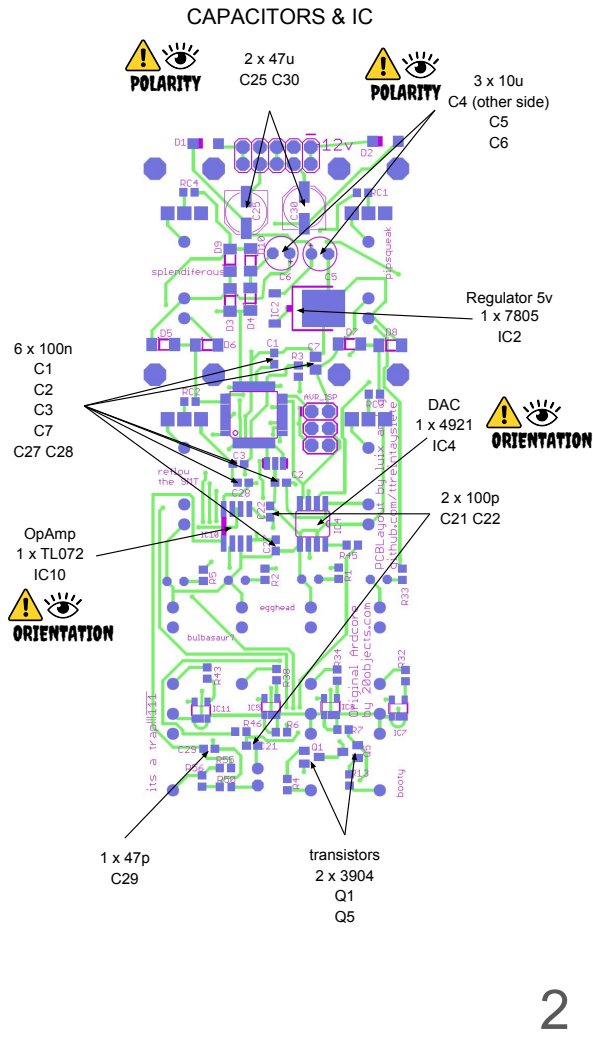
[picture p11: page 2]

## 1. Place the potentiometers, minijacks and leds (without soldering). Place the panel and all the

nuts on the components.

## 2. Solder the potentiometers, minijacks and leds

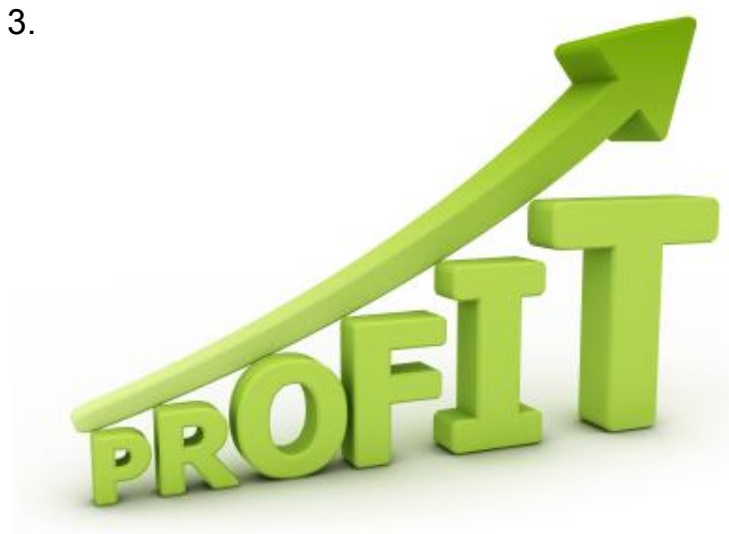
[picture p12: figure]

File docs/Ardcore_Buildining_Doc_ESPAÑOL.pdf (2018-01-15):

## RESISTENCIAS Y DIODOS

# POLARIDAD

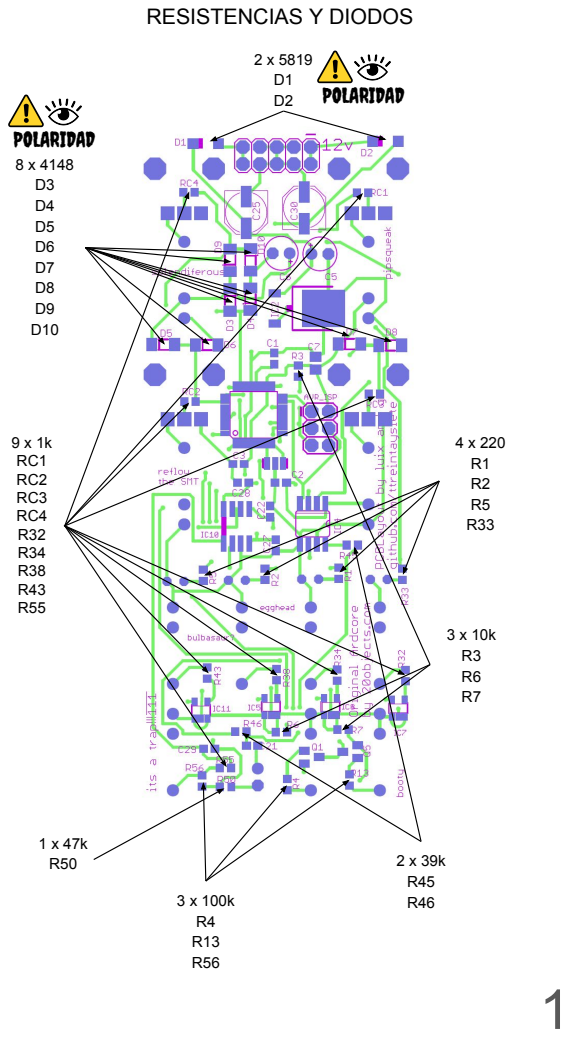
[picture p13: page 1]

## CONDENSADORES Y IC

POLARIDAD | POLARIDAD

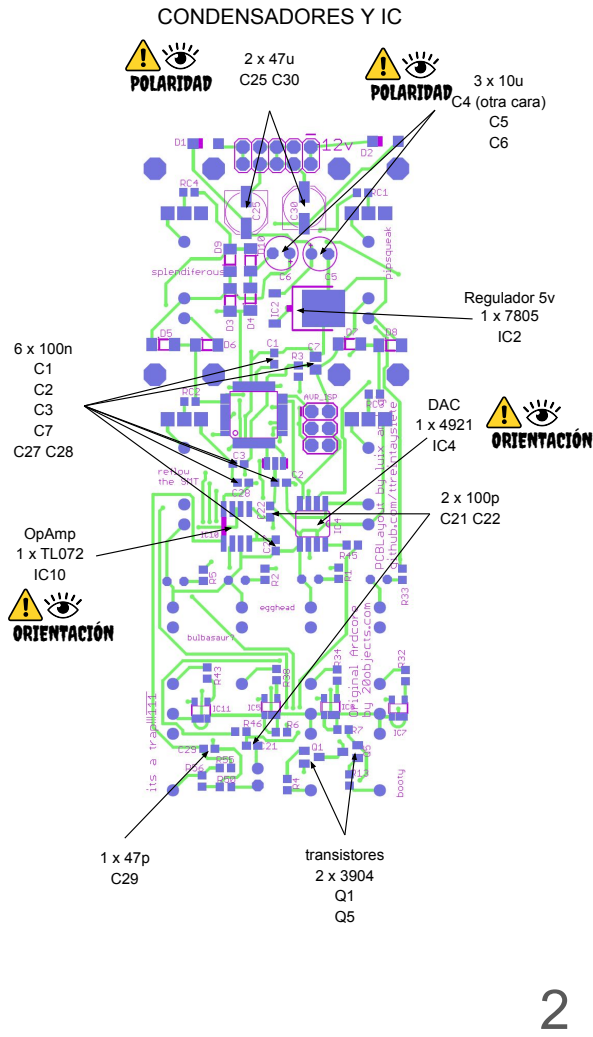
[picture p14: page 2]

## 1. Colocar los potenciómetros, minijacks y leds (sin

soldar). | Poner el | panel | y | atornillar los
componentes.

## 2. Soldar los potenciómetros, minijacks y leds

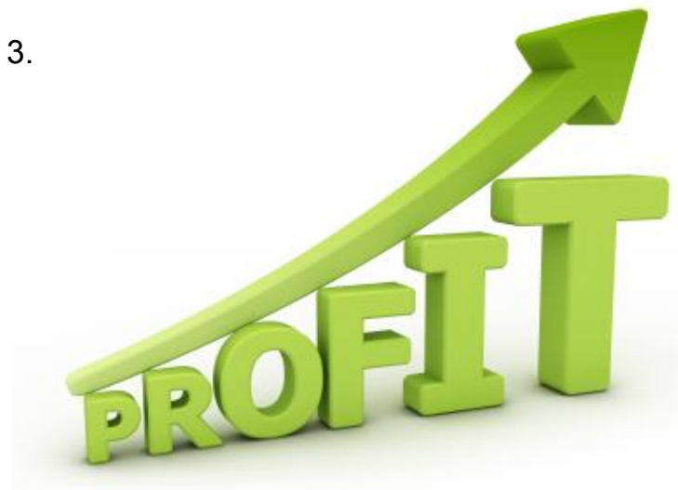
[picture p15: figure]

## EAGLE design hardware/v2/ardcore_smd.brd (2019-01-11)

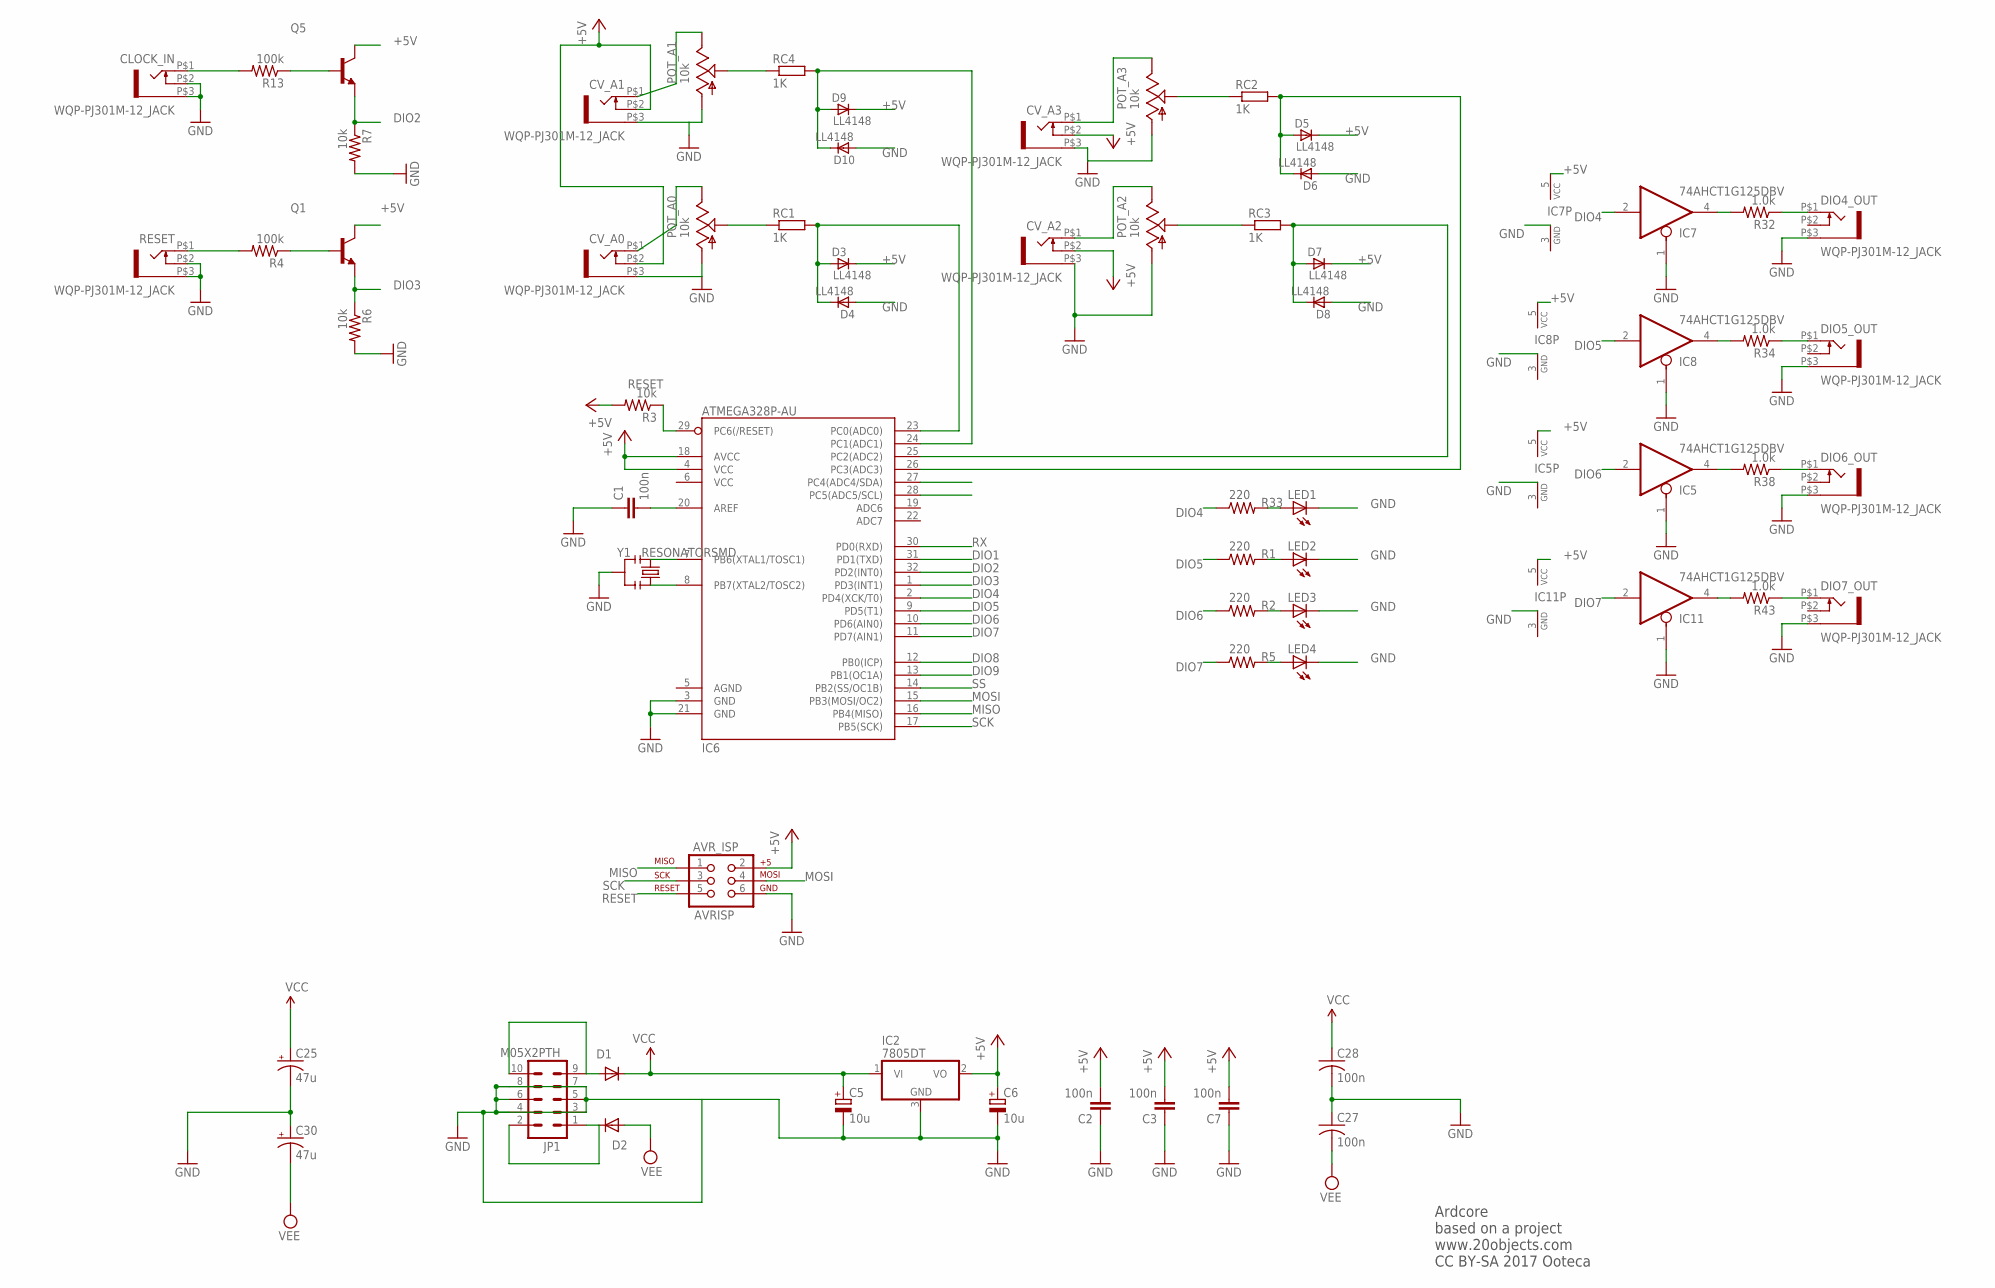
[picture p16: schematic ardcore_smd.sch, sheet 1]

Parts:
AVR_ISP: AVRISP; 2X3
C1, C2, C3, C27, C28: 100n; C0603
C5, C6: 10u; E2,5-5
C7: 100n; C0805
C25, C30: 47u; PANASONIC_D
CLOCK_IN: WQP-PJ301M-12_JACK
CV_A0, CV_A1, CV_A2, CV_A3: WQP-PJ301M-12_JACK
D1, D2: 1N5819; SOD123
D3, D4, D5, D6, D7, D8, D9, D10: LL4148; SOD80_DO213AA_MINIMELF
DIO4_OUT, DIO5_OUT, DIO6_OUT, DIO7_OUT: WQP-PJ301M-12_JACK
IC2: 7805DT; TO252
IC5, IC7, IC8, IC11: 74AHCT1G125DBV; SOT23-5
IC6: ATMEGA328P-AU; TQFP32-08
JP1: M05X2PTH; AVR_ICSP
LED1, LED2, LED3, LED4: LED3MM
POT_A0, POT_A1, POT_A2, POT_A3: 10k; ALPS_POT_VERTICAL
Q1, Q5: MMBT3904LT1-NPN-SOT23-BEC; SOT23-BEC
R1, R2, R5, R33: 220; R0603
R3, R6, R7: 10k; R0603
R4, R13: 100k; R0603
R32, R34, R38, R43: 1.0k; R0603
RC1, RC2, RC3, RC4: 1K; R0603
RESET: WQP-PJ301M-12_JACK
Y1: RESONATORSMD; RESONATOR-SMD

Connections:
+5V: AVR_ISP.2, C2.2, C3.2, C6.+, C7.2, CV_A0.P$2 (3), CV_A1.P$2 (3), CV_A2.P$2 (3), CV_A3.P$2 (3), D3.C, D5.C, D7.C, D9.C, IC2.2 (VO), IC5.5 (VCC), IC6.4 (VCC), IC6.18 (AVCC), IC7.5 (VCC), IC8.5 (VCC), IC11.5 (VCC), Q1.C, Q5.C, R3.2; also elsewhere on the board
ANI1: D9.A, D10.C, IC6.24 (PC1(ADC1)), RC4.2
ANI2: D3.A, D4.C, IC6.23 (PC0(ADC0)), RC1.2
ANI3: D5.A, D6.C, IC6.26 (PC3(ADC3)), RC2.2
ANI4: D7.A, D8.C, IC6.25 (PC2(ADC2)), RC3.2
DIO1: IC6.31 (PD1(TXD))
DIO2: IC6.32 (PD2(INT0)), Q5.E, R7.1
DIO3: IC6.1 (PD3(INT1)), Q1.E, R6.1
DIO4: IC6.2 (PD4(XCK/T0)), IC7.2 (I), R33.1
DIO5: IC6.9 (PD5(T1)), IC8.2 (I), R1.1
DIO6: IC5.2 (I), IC6.10 (PD6(AIN0)), R2.1
DIO7: IC6.11 (PD7(AIN1)), IC11.2 (I), R5.1
DIO8: IC6.12 (PB0(ICP))
DIO9: IC6.13 (PB1(OC1A))
GND: AVR_ISP.6, C1.1, C2.1, C3.1, C5.-, C6.-, C7.1, C25.-, C27.1, C28.2, C30.+, CLOCK_IN.P$2 (3), CLOCK_IN.P$3 (1), CV_A0.P$3 (1), CV_A1.P$3 (1), CV_A2.P$3 (1), CV_A3.P$3 (1), D4.A, D6.A, D8.A, D10.A, DIO4_OUT.P$3 (1), DIO5_OUT.P$3 (1), DIO6_OUT.P$3 (1), DIO7_OUT.P$3 (1), IC2.3 (GND), IC5.1 (OE), IC5.3 (GND), IC6.3 (GND), IC6.21 (GND), IC7.1 (OE), IC7.3 (GND), IC8.1 (OE), IC8.3 (GND), IC11.1 (OE), IC11.3 (GND), JP1.3, JP1.4, JP1.5, JP1.6, JP1.7, JP1.8, LED1.K (C), LED2.K (C), LED3.K (C), LED4.K (C), POT_A0.P$3 (A), POT_A1.P$3 (A), POT_A2.P$3 (A), POT_A3.P$3 (A), R6.2, R7.2, RESET.P$2 (3), RESET.P$3 (1), Y1.2; also elsewhere on the board
MISO: AVR_ISP.1, IC6.16 (PB4(MISO))
MOSI: AVR_ISP.4, IC6.15 (PB3(MOSI/OC2)); also elsewhere on the board
unnamed: CV_A2.P$1 (2), POT_A2.P$1 (E)
unnamed: D1.A, JP1.9, JP1.10
unnamed: D2.C, JP1.1, JP1.2
unnamed: DIO6_OUT.P$1 (2), R38.1
unnamed: C1.2, IC6.20 (AREF)
unnamed: DIO5_OUT.P$1 (2), R34.1
unnamed: DIO7_OUT.P$1 (2), R43.1
unnamed: DIO4_OUT.P$1 (2), R32.1
unnamed: CV_A3.P$1 (2), POT_A3.P$1 (E)
unnamed: IC7.4 (O), R32.2
unnamed: Q1.B, R4.1
unnamed: R4.2, RESET.P$1 (2)
unnamed: IC8.4 (O), R34.2
unnamed: Q5.B, R13.1
unnamed: IC6.7 (PB6(XTAL1/TOSC1)), Y1.1
unnamed: IC6.8 (PB7(XTAL2/TOSC2)), Y1.3
unnamed: LED2.A, R1.2
unnamed: LED3.A, R2.2
unnamed: CLOCK_IN.P$1 (2), R13.2
unnamed: LED4.A, R5.2
unnamed: CV_A0.P$1 (2), POT_A0.P$1 (E)
unnamed: POT_A3.P$2 (S), RC2.1
unnamed: CV_A1.P$1 (2), POT_A1.P$1 (E)
unnamed: POT_A2.P$2 (S), RC3.1
unnamed: POT_A0.P$2 (S), RC1.1
unnamed: POT_A1.P$2 (S), RC4.1
unnamed: IC5.4 (O), R38.2
unnamed: IC11.4 (O), R43.2
unnamed: LED1.A, R33.2
RESET: AVR_ISP.5, IC6.29 (PC6(/RESET)), R3.1
RX: IC6.30 (PD0(RXD))
SCK: AVR_ISP.3, IC6.17 (PB5(SCK)); also elsewhere on the board
SS: IC6.14 (PB2(SS/OC1B)); also elsewhere on the board
SW_BLUE: IC6.28 (PC5(ADC5/SCL))
SW_YELLOW: IC6.27 (PC4(ADC4/SDA))
VCC: C5.+, C25.+, C28.1, D1.C, IC2.1 (VI); also elsewhere on the board
VEE: C27.2, C30.-, D2.A; also elsewhere on the board

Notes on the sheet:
Ardcore based on a project www.20objects.com CC BY-SA 2017 Ooteca

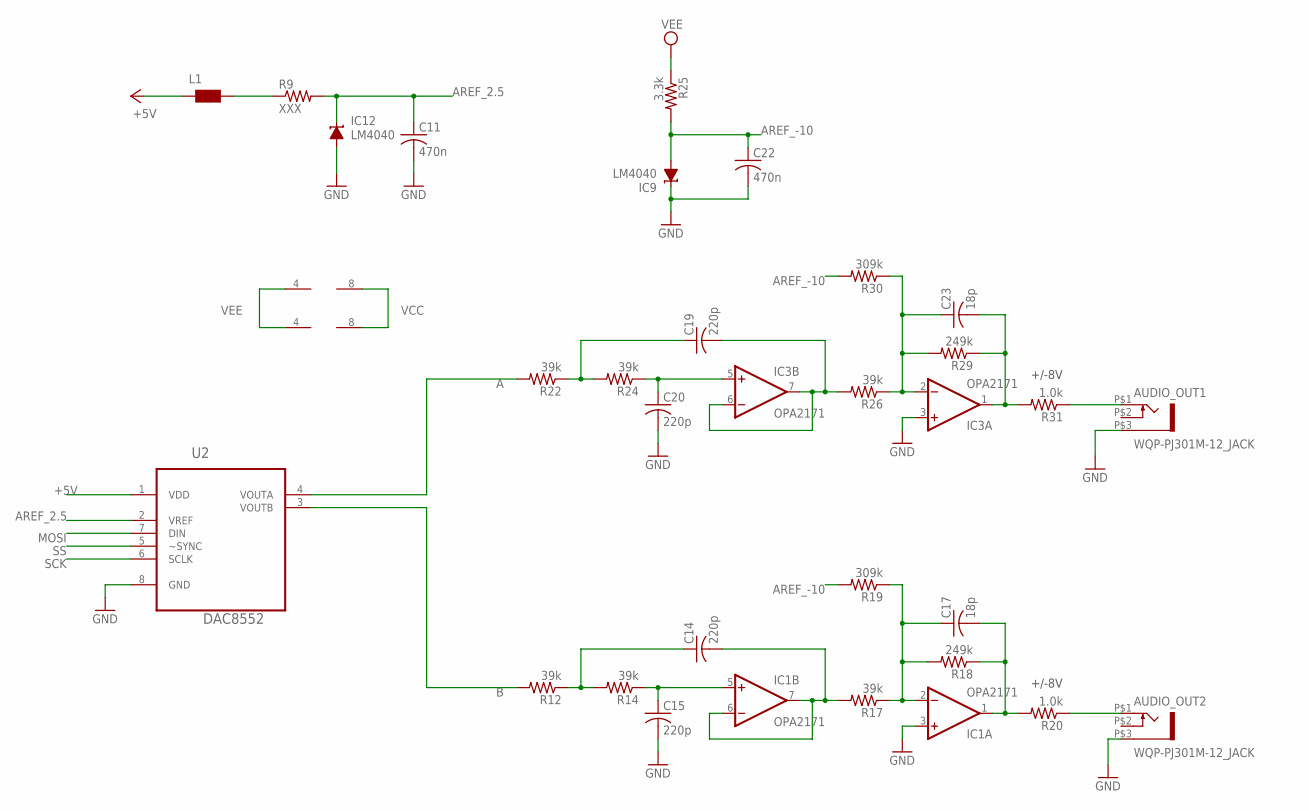
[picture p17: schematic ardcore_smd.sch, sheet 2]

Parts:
AUDIO_OUT1, AUDIO_OUT2: WQP-PJ301M-12_JACK
C11, C22: 470n; C0603
C14, C15, C19, C20: 220p; C0603
C17, C23: 18p; C0603
IC1, IC3: OPA2171; SO08
IC9, IC12: LM4040; DBZ_R-PDSO-G3
L1: WE-CBF_0603; 0603
R9: XXX; R0603
R12, R14, R17, R22, R24, R26: 39k; R0603
R18, R29: 249k; R0603
R19, R30: 309k; R0603
R20, R31: 1.0k; R0603
R25: 3.3k; R0603
U2: DAC8552; SOP65P490X110-8N

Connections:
+5V: L1.1, U2.1 (VDD); also elsewhere on the board
A: R22.2, U2.4 (VOUTA)
AREF_2.5: C11.1, IC12.1 (C), R9.2, U2.2 (VREF)
AREF_-10: C22.1, IC9.2 (A), R19.2, R25.2, R30.2
B: R12.2, U2.3 (VOUTB)
BI_OUT: C17.2, IC1.1 (OUT), R18.1, R20.2
BI_OUT1: C23.2, IC3.1 (OUT), R29.1, R31.2
F_CV: C17.1, IC1.2 (-IN), R17.1, R18.2, R19.1
F_CV1: C23.1, IC3.2 (-IN), R26.1, R29.2, R30.1
GND: AUDIO_OUT1.P$3 (1), AUDIO_OUT2.P$3 (1), C11.2, C15.2, C20.2, C22.2, IC1.3 (+IN), IC3.3 (+IN), IC9.1 (C), IC12.2 (A), U2.8 (GND); also elsewhere on the board
MOSI: U2.7 (DIN); also elsewhere on the board
unnamed: C14.1, R12.1, R14.2
unnamed: AUDIO_OUT2.P$1 (2), R20.1
unnamed: C19.2, IC3.6 (-IN), IC3.7 (OUT), R26.2
unnamed: C20.1, IC3.5 (+IN), R24.1
unnamed: C19.1, R22.1, R24.2
unnamed: AUDIO_OUT1.P$1 (2), R31.1
unnamed: L1.2, R9.1
unnamed: C14.2, IC1.6 (-IN), IC1.7 (OUT), R17.2
unnamed: C15.1, IC1.5 (+IN), R14.1
SCK: U2.6 (SCLK); also elsewhere on the board
SS: U2.5 (~SYNC); also elsewhere on the board
VCC: IC1.8 (V+), IC3.8 (V+); also elsewhere on the board
VEE: IC1.4 (V-), IC3.4 (V-), R25.1; also elsewhere on the board

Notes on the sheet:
+/-8V

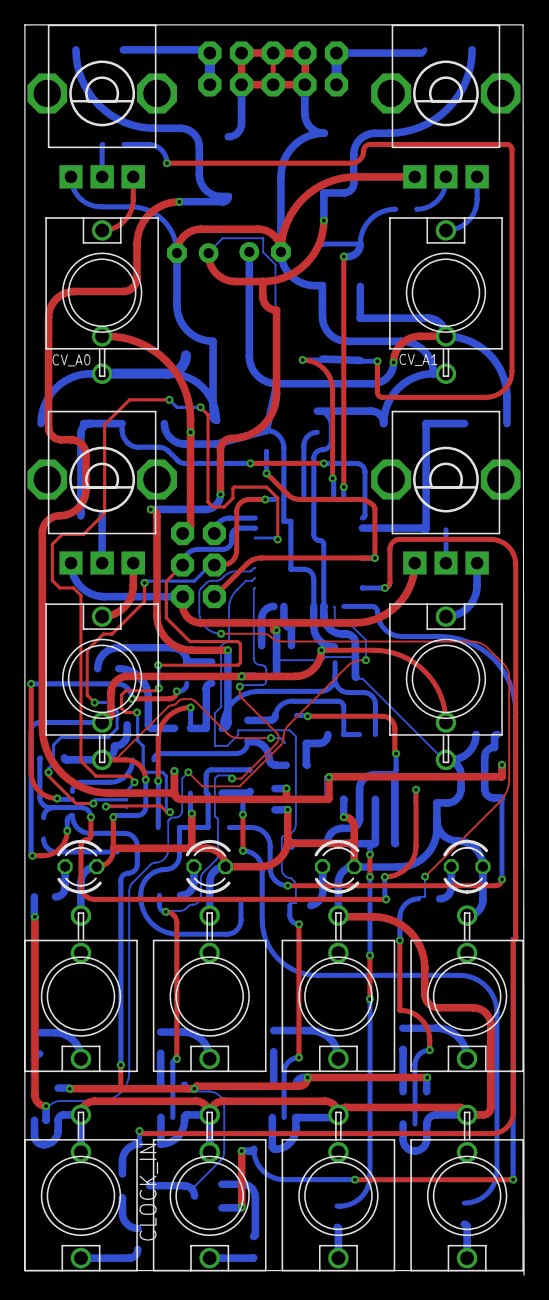
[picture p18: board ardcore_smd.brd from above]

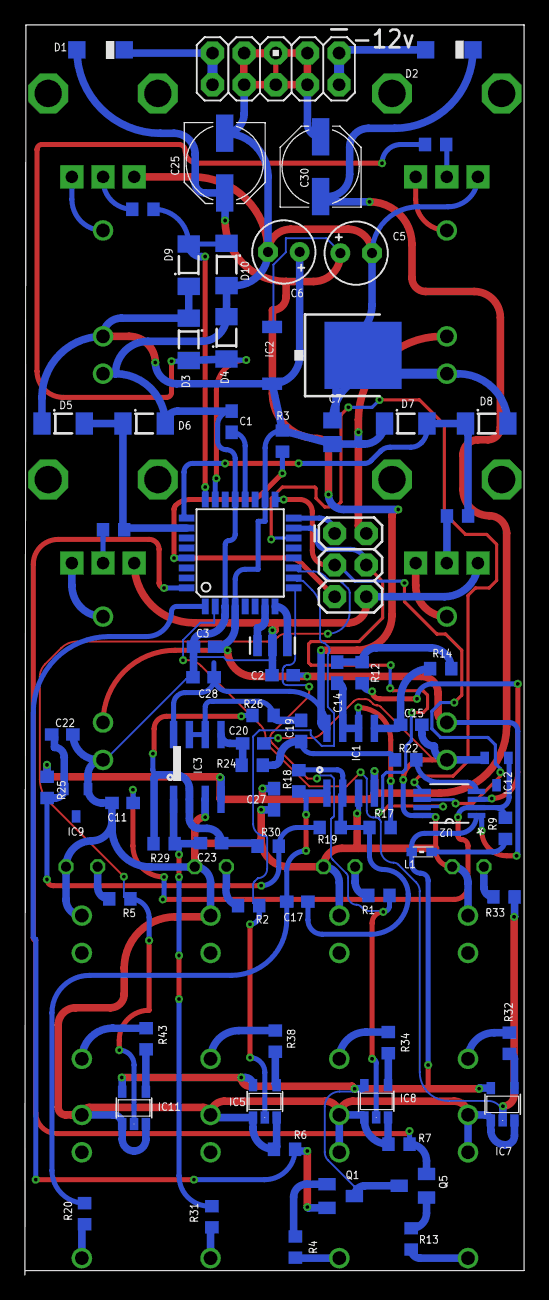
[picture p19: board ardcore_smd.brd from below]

Board: 2 copper layers, 40.1 x 100.4 mm, 96 parts (76 on the bottom side), 65 nets.

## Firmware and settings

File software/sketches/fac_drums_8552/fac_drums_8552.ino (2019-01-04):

//  ============================================================
//
//  Program: ArdCore Drum Sample Player
//
//  Description:
//
//    This is a very lo-fi drum sample player for 8 sounds.
//
//  I/O Usage:
//    Knob A0: Sound selector (summed with input A2)
//    Knob A1: Pitch (summed with input A3). Center value is normal pitch.
//    Analog In A2: Sound selection (summed with value of knob A0)
//    Analog In A3: VC Pitch (summed with value of knob A1)
//    Digital Out D0: Not used
//    Digital Out D1: Not used
//    Clock In: Trigger sound
//    Analog Out: Audio out
//
//    This sketch was generated by the drum sketch
//    generator, programmed by Alfonso Alba (fac)
//    E-mail: shadowfac@hotmail.com
//
//  ============================================================
//
//  License:
//
//  This software is licensed under the Creative Commons
//  Attribution-NonCommercial license. This license allows you
//  to tweak and build upon the code for non-commercial purposes,
//  without the requirement to license derivative works on the
//  same terms. If you wish to use this (or derived) work for
//  commercial work, please contact 20 Objects LLC at our website
//  (www.20objects.com).
//
//  For more information on the Creative Commons CC BY-NC license,
//  visit http://creativecommons.org/licenses/
//
//  ================= start of global section ==================


// Here we include the sample data files, which were automatically
// generated by a custom C program. In the future, I may release
// an executable version of this program so you can make your
// own sample banks

#include <SPI.h>
#include <DAC855X.h>

DAC855X dac;

#include <avr/pgmspace.h>

#include "pitch_table.h"
#include "sample0.h"
#include "sample1.h"
#include "sample2.h"
#include "sample3.h"
#include "sample4.h"
#include "sample5.h"
#include "sample6.h"
#include "sample7.h"

//  constants related to the Arduino Nano pin use
#define clkIn      2    // the digital (clock) input
#define digPin0    4    // the digital output pin D0
#define digPin1    5    // the digital output pin D1
#define digPin2    6    // the digital output pin D2
#define digPin3    7    // the digital output pin D3

//  constants related to the sample player
#define NUM_SAMPLES      8      // number of samples stored in flash RAM
#define MAX_SAMPLE_SIZE  1632   // maximum length of each sound

//  This array stores pointers to sample data in flash RAM
prog_uchar *sample_data[NUM_SAMPLES] = {
  sample0_data, sample1_data, sample2_data, sample3_data,
  sample4_data, sample5_data, sample6_data, sample7_data
};

//  This one stores the size of each sample
short sample_size[NUM_SAMPLES] = {
  sample0_size, sample1_size, sample2_size, sample3_size,
  sample4_size, sample5_size, sample6_size, sample7_size
};

//  This one stores the samplerate of each sound in samples per microsecond
float sample_fs_micro[NUM_SAMPLES] = {
  sample0_fs_micro, sample1_fs_micro, sample2_fs_micro, sample3_fs_micro,
  sample4_fs_micro, sample5_fs_micro, sample6_fs_micro, sample7_fs_micro
};


//  This is the SRAM buffer where the sound being played is stored
unsigned char sample[MAX_SAMPLE_SIZE];

//  Some global variables
char curSample = -1;    // current sample number (0 to NUM_SAMPLES-1)
short curSize = 0;      // size in samples of current sound
long curFSmicro = 0;   // sample rate of current sound
float envStart = 0;     // offset where decay starts (in samples)

short curVal0 = 0;      // stores the value of analog input 0
short curVal1 = 0;      // stores the value of analog input 1
short curVal2 = 0;      // stores the value of analog input 2
short curVal3 = 0;      // stores the value of analog input 3
unsigned long curTime = 0;  // current time in microseconds
unsigned long trigTime = 0; // time at which the sound was triggered
char trigState = 0;         // indicates if a sound is being played

short digi0Counter = 0;
short digi1Counter = 0;
short digi2Counter = 0;
short digi3Counter = 0;

short digi0Trigger = 2;
short digi1Trigger = 4;

//  variables for interrupt handling of the clock input
volatile char clkState = LOW;


// This function updates the sample buffer when a new sound is selected
// and also computes the playback samplerate according to the pitch
// Inputs: n = new sample number, pitch = pitch factor
void UpdateSample(int n, long pitch) {
  // limit n according to the maximum number of stored sounds
  if (n >= NUM_SAMPLES) n = NUM_SAMPLES - 1;

  // check if we really need to load a new waveform
  if (n != curSample) {
    // samples stored in flash RAM may be larger than the available buffer
    // so we must crop the sample when needed
    curSize = (sample_size[n] < MAX_SAMPLE_SIZE) ? sample_size[n] : MAX_SAMPLE_SIZE;

    // copy the sample in flash RAM to the buffer in SRAM
    memcpy_P(sample, sample_data[n], curSize);

    // update current sample number
    curSample = n;
  }

  // compute the playback samplerate taking the pitch factor into account;
  // this is specified in samples per microsecond
  curFSmicro = (long)(sample_fs_micro[curSample] * pitch);
}


//  ==================== start of setup() ======================

//  This setup routine should be used in any ArdCore sketch that
//  you choose to write; it sets up the pin usage, and sets up
//  initial state. Failure to properly set up the pin usage may
//  lead to damaging the Arduino hardware, or at the very least
//  cause your program to be unstable.

void setup()
{
  // set up the digital (clock) input
  pinMode(clkIn, INPUT);

  // set up the digital outputs
  pinMode(digPin0, OUTPUT);
  digitalWrite(digPin0, LOW);
  pinMode(digPin1, OUTPUT);
  digitalWrite(digPin1, LOW);
  pinMode(digPin2, OUTPUT);
  digitalWrite(digPin3, LOW);
  pinMode(digPin3, OUTPUT);
  digitalWrite(digPin3, LOW);

  // Make sure some sample is loaded
  UpdateSample(0, 1);
  dacOutputFast(128);

  dac.setPins(11, 13, 10);
  dac.initializeDAC855X();
  
}


//  This is the main loop

void loop()
{
  unsigned long deltaT = 0;;
  long p, s, n, out = 128;

  // check to see if the clock as been set
  if (clkState == HIGH) {

    digi0Counter++;
    digi1Counter++;
    digi2Counter++;
    digi3Counter++;
    
    if(digi0Counter >= digi0Trigger){
      digi0Counter=0;
      digitalWrite(digPin0, HIGH);    
    }
    
    if(digi1Counter >= digi1Trigger){
      digi1Counter=0;
      digitalWrite(digPin1, HIGH);    
    }
    
    if(digi2Counter >= map(analogRead(2),0,1014,1,12)){
      digi2Counter=0;
      digitalWrite(digPin2, HIGH);    
    }

    if(digi3Counter >= map(analogRead(3),0,1014,1,12)){
      digi3Counter=0;
      digitalWrite(digPin3, HIGH);    
    }    

    clkState = LOW;      // clock pulse acknowledged
    trigState = 1;       // a sound has been triggered
    trigTime = micros(); // remember starting time

    // Poll the analog inputs and update their values
    // This is only done at sample-start to save resources
    curVal0 = deJitter(analogRead(0), curVal0);
    curVal1 = deJitter(analogRead(1), curVal1);

    // Read pitch factor from lookup table
    p = pgm_read_dword_near(pitch_table + (curVal1));

    // Load new sample if necessary and update playback samplerate
    //UpdateSample((curVal0 + curVal2) >> 7, p);
    UpdateSample(map(curVal0, 0, 1023, 0, NUM_SAMPLES), p);

  }

  // Check if a sound is being played
  if (trigState) {
    // Obtain current time
    curTime = micros();

    // Obtain time since the sound was triggered;
    // a correction is made in the unlikely case the clock overflows
    deltaT = (curTime >= trigTime) ? (curTime - trigTime) : ((0xFFFFFFFF - trigTime + curTime) + 1);

    // Convert time to samples and separate integer from fractional part
    s = deltaT * curFSmicro;
    n = s >> 16;
    p = s & 0xFFFF;

    // Check if the sound hasn't reached its end
    if (n < curSize - 1) {
      // Compute output by linear interpolation and apply envelope
      out = ((65536 - p) * sample[n] + p * sample[n+1]) >> 16;
    } else {
      out = 128;
      trigState = 0;  // sample has ended
    }

    dacOutputFast(out);
  }
  
  digitalWrite(digPin0, LOW);
  digitalWrite(digPin1, LOW);
  digitalWrite(digPin2, LOW);
  digitalWrite(digPin3, LOW);
  
}


//  =================== convenience routines ===================

//  These routines are some things you will need to use for
//  various functions of the hardware. Explanations are provided
//  to help you know when to use them.

//  isr() - quickly handle interrupts from the clock input
//  ------------------------------------------------------
void isr()
{
  // Note: you don't want to spend a lot of time here, because
  // it interrupts the activity of the rest of your program.
  // In most cases, you just want to set a variable and get
  // out.
  clkState = HIGH;
}

//  dacOutput(long) - deal with the DAC output
//  ------------------------------------------
void dacOutput(long v)
{
  dac.outputA(v*4);
}


// This routine was taken from the Ardcore Oscillator example
// and it's supposed to be faster than dacOutput
void dacOutputFast(long v)
{
  dac.outputA(v*64);
}


//  deJitter(int, int) - smooth jitter input
//  ----------------------------------------
int deJitter(int v, int test)
{
  // this routine just make sure we have a significant value
  // change before we bother implementing it. This is useful
  // for cleaning up jittery analog inputs.
  if (abs(v - test) > 8) {
    return v;
  }
  return test;
}

//  ===================== end of program =======================

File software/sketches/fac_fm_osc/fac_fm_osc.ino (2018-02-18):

#include <SPI.h>
#include <DAC_MCP49xx.h>
DAC_MCP49xx dac(DAC_MCP49xx::MCP4921, 10);

//  ============================================================
//
//  Program: ArdCore FM Oscillator
//
//  This program implements two sinewave oscillators in an
//  FM modulator/carrier configuration.
//
//  I/O Usage:
//    Knob A0: Main pitch
//    Knob A1: Modulator pitch offset
//    Analog In A2: 1 V/Oct pitch input
//    Analog In A3: Modulation index (depth)
//    Digital Out D0: Not used
//    Digital Out D1: Not used
//    Clock In: Carrier hard sync 
//    Analog Out: Audio out
//
//    This sketch was programmed by Alfonso Alba (fac)
//    E-mail: shadowfac@hotmail.com
//
//  Created:  March 2012
//  Modified: 
//
//  ============================================================
//
//  License:
//
//  This software is licensed under the Creative Commons
//  Attribution-NonCommercial license. This license allows you
//  to tweak and build upon the code for non-commercial purposes,
//  without the requirement to license derivative works on the
//  same terms. If you wish to use this (or derived) work for
//  commercial work, please contact 20 Objects LLC at our website
//  (www.20objects.com).
//
//  For more information on the Creative Commons CC BY-NC license,
//  visit http://creativecommons.org/licenses/
//
//  ================= start of global section ==================



#define cbi(sfr, bit) (_SFR_BYTE(sfr) &= ~_BV(bit))
#define sbi(sfr, bit) (_SFR_BYTE(sfr) |= _BV(bit))

#include <avr/pgmspace.h>

#include "sine_table.h"
#include "pitch_table.h"
#include "offset_table.h"
#include "cv_table.h"

//  constants related to the Arduino Nano pin use
#define clkIn      2    // the digital (clock) input
#define digPin0    4    // the digital output pin D0
#define digPin1    5    // the digital output pin D1
#define digPin2    6    // the digital output pin D1
#define digPin3    7    // the digital output pin D1
#define pinOffset  5    // the first DAC pin (from 5-12)


//  ==================== start of setup() ======================

//  This setup routine should be used in any ArdCore sketch that
//  you choose to write; it sets up the pin usage, and sets up
//  initial state. Failure to properly set up the pin usage may
//  lead to damaging the Arduino hardware, or at the very least
//  cause your program to be unstable.

void setup() 
{
  // if you need to send data back to your computer, you need
  // to open the serial device. Otherwise, comment this line out.
  Serial.begin(9600);

  // set up the digital (clock) input
  pinMode(clkIn, INPUT);

  // set up the digital outputs
  pinMode(digPin0, OUTPUT);
  digitalWrite(digPin0, LOW);
  pinMode(digPin1, OUTPUT);
  digitalWrite(digPin1, LOW);
  
  pinMode(digPin2, OUTPUT);
  digitalWrite(digPin2, LOW);
  pinMode(digPin3, OUTPUT);
  digitalWrite(digPin3, LOW);

  // set up the 8-bit DAC output pins
  for (int i=0; i<8; i++) {
    pinMode(pinOffset+i, OUTPUT);
    digitalWrite(pinOffset+i, LOW);
  }

  // set up an interrupt handler for the clock in. If you
  // aren't going to use clock input, you should probably
  // comment out this call.
  // Note: Interrupt 0 is for pin 2 (clkIn)
  attachInterrupt(0, isr, RISING);

  // Timer2 PWM Mode set to fast PWM 
  cbi (TCCR2A, COM2A0);
  sbi (TCCR2A, COM2A1);
  sbi (TCCR2A, WGM20);
  sbi (TCCR2A, WGM21);
  cbi (TCCR2B, WGM22);
  // Timer2 Clock Prescaler to : 1 
  sbi (TCCR2B, CS20);
  cbi (TCCR2B, CS21);
  cbi (TCCR2B, CS22);

  // Timer2 PWM Port Enable
  sbi(DDRB,3);                    // set digital pin 11 to output

  //cli();                         // disable interrupts to avoid distortion
  cbi (TIMSK0,TOIE0);              // disable Timer0 !!! delay is off now
  sbi (TIMSK2,TOIE2);              // enable Timer2 Interrupt

  dac.setBuffer(true);        //  Set FALSE for 5V vref.
  dac.setGain(1);             //  "1" for 5V vref. "2" for 2.5V vref.
  dac.setPortWrite(true); 
}


//  This is the main loop

boolean div1 = false, div2 = false, poll_inputs = false;
long n, p, out;

//  Some global variables
short curVal0 = 0;      // stores the value of analog input 0
short curVal1 = 0;      // stores the value of analog input 1
short curVal2 = 0;      // stores the value of analog input 2
short curVal3 = 0;      // stores the value of analog input 3

long m_phase = 0;      // modulator phase (12.20 fixed point)
long c_phase = 0;      // carrier phase (12.20 fixed point)
long m_dphase = 0;     // modulator frequency (12.20 fixed point)
long c_dphase = 0;     // carrier frequency (12.20 fixed point)
long m_depth = 0;      // modulation depth (22.10 fixed point)

long dphase;


void loop() {
  unsigned long ul1, ul2, ul3;
  float freq;

  //  if (poll_inputs) {
  poll_inputs = false;

  curVal0 = deJitter(analogRead(0), curVal0);
  curVal1 = deJitter(analogRead(1), curVal1);
  curVal2 = deJitter(analogRead(2), curVal2);
  curVal3 = deJitter(analogRead(3), curVal3);

  ul1 = pgm_read_dword_near(pitch_table + curVal0);
  freq = *((float *)&ul1);
  ul2 = pgm_read_dword_near(cv_table + curVal2);
  freq *= *((float *)&ul2);

  freq *= ((long)1 << 20);

  // obtain main frequency 
  c_dphase = (long)(freq + 0.5);

  // obtain modulator frequency
  ul3 = pgm_read_dword_near(offset_table + curVal1);
  m_dphase = (long)(freq * *((float *)&ul3) + 0.5);

  // obtain modulation depth
  m_depth = curVal3;
  //  }
}


ISR(TIMER2_OVF_vect) {
  div1 = !div1;
  if (div1) {
    div2 = !div2;
    if (div2) {
      m_phase += m_dphase;
      if (m_phase >= 1073741824) m_phase -= 1073741824;  
      out = sine_wave[m_phase >> 20];  


      // f_c = f_c * (1 + I * out_m), where I in (0,1) and out_m in (-1, 1)
      dphase = (c_dphase >> 10) * ((long)1024 + ((out * m_depth) >> 5));
      c_phase += dphase;
      if (c_phase >= 1073741824) c_phase -= 1073741824;  
      out = sine_wave[c_phase >> 20];
      dacOutput(out + 128);      
    }
  }
  
  
  if(out > 0){
    digitalWrite(digPin1, true);
  }
  else{
    digitalWrite(digPin1, false);
  }

  if(out > 0){
    digitalWrite(digPin2, true);
  }
  else{
    digitalWrite(digPin2, false);
  }
  
  if(dphase > 0){
    digitalWrite(digPin3,true);
  }
  else {
    digitalWrite(digPin3,false);
  }
  
  
  if(dphase > 0){
    digitalWrite(digPin0,true);
  }
  else {
    digitalWrite(digPin0,false);
  }
  
}


//  =================== convenience routines ===================

//  These routines are some things you will need to use for
//  various functions of the hardware. Explanations are provided
//  to help you know when to use them.

//  isr() - quickly handle interrupts from the clock input
//  ------------------------------------------------------
void isr()
{
  // Note: you don't want to spend a lot of time here, because
  // it interrupts the activity of the rest of your program.
  // In most cases, you just want to set a variable and get
  // out.
  //  poll_inputs = true;
  c_phase = 0;
}
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

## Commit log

2017-09-28 Adding voltage controlled clockdivider to fac drums sketch
2017-10-02 Adding building guide and bom
2017-10-02 Adding fixes to BOM
2017-10-02 Adding fix for bom
2017-10-02 Adding schematics, boards and Gerbers
    [ardcore_smd.brd, ardcore_smd.sch, ardcore_smd_panel.brd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]
2017-11-20 Changing R50 to 47k to have better gain on output, this was corrected on the Schematics, Board, BOM list and Mouser Project link, also fix in the __dac.setGain(1);__ instruction of the DAC, to use 5v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
    [ardcore_smd.brd, ardcore_smd.sch]
2017-11-20 Changing exported bom CSV
    [exported_bom.csv]
2018-01-12 Update BUILDING.md
    Added note to connect power during programming of fuses or sketches
2018-02-06 Adding fix for facdrums
    [AC24_SimpleVCO.ino, fac_drums.ino]
2018-04-01 Adding version 2 files
    [ardcore_smd.brd, ardcore_smd.sch, ardcore_smd_panel.brd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]
2018-04-02 New components
    [ardcore_smd.brd, ardcore_smd.sch]
2018-04-06 removing 3v3 reg
    [ardcore_smd.brd, ardcore_smd.sch]
2018-04-07 almost routed
    [ardcore_smd.brd]
2018-05-02 Adding version
    [ardcore_smd.brd, ardcore_smd.sch, ardcore_smd_panel.brd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]
2018-05-02 changes on panel
    [ardcore_smd.sch, ardcore_smd_panel.brd, ardcore_smd_panel.sch]
2019-01-04 Adding v2 fixed gerbers
    [ardcore_smd.GBL, ardcore_smd.GBO, ardcore_smd.GBP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]
2019-01-11 updating gerbers
    [ardcore_smd.GBL, ardcore_smd.GBO, ardcore_smd.GBP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]
